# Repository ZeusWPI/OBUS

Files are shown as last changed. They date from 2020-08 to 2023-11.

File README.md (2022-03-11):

# Ontmijnen van een Bom vereist Uitstekende Samenwerking

You see an armed time bomb but don't know how to disarm it. Your friends found a manual to defuse the bomb and you have them on call. This is the premise of the game OBUS, a hardware project by [Zeus WPI](https://zeus.ugent.be). Inspired by the amazing software game [Keep Talking and Nobody Explodes](https://www.keeptalkinggame.com/).

## Get started writing a module

These are the instructions for building your own OBUS module with an Arduino Nano v3 and the custom PCB. If
you're using other hardware, you might need to do some things differently.

0. (Read the "[Getting started guide](docs/GETTING_STARTED.md)" to get a general idea of how OBUS works.)
1. [Install](https://www.arduino.cc/en/Guide/#install-the-arduino-desktop-ide) the Arduino IDE.
2. Clone this repository with Git in a permanent location on your drive.
3. Symlink the library: `ln -s /ABSOLUTE/PATH/TO/REPO/lib /PATH/TO/Arduino/libraries/obus`
  (on most Linux distro's, this the Arduino folder is in `$HOME/Arduino`)
4. Follow [these steps](https://github.com/autowp/arduino-mcp2515/#software-usage) to install the CAN library
5. Execute `./src/new_module.sh` to create a new module. When asked for a type, you'll probably want to choose 'puzzle'.
6. Edit the newly generated .ino file, either in the Arduino IDE or in your own editor.
7. In the Arduino IDE, select the correct board (Arduino Nano) and processor (ATmega328P (Old Bootloader)). After that,
   flash your code to the Arduino and test it out.
8. On some Linux distributions, you'll need to prevent BRLTTY from taking over the serial adapter because BRLTTY thinks it's a Braille keyboard. You can do this by uninstalling it (`pacman -R brltty`) or by [disabling it and then rebooting](https://unix.stackexchange.com/questions/670636/unable-to-use-usb-dongle-based-on-usb-serial-converter-chip).
9. If you get permission errors, try adding yourself to the dialout or uucp (Arch Linux) group

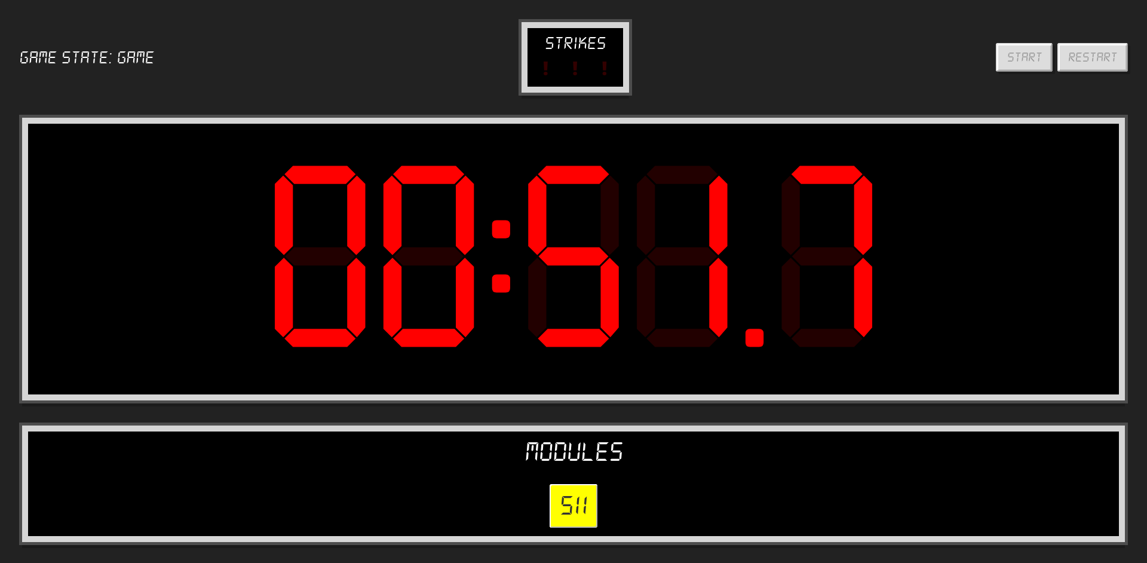
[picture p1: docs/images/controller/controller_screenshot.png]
A screenshot of the OBUS controller web page, showing a countdown timer, a list of connected modules and the strikes


## Background
### Game

The game is played by at least two players. The goal is to defuse a bomb,
this is accomplished by defusing every module on that bomb before the bomb
timer runs out.

There are two roles:

- Expert: this person can read the manual about how to defuse the bomb, but cannot see nor interact with the bomb
- Defuser: this person can see and interact with the bomb, but cannot read the manual

These two roles can communicate with each other. To successfully defuse the bomb, they must
communicate efficiently and clearly. If a mistake is made, the team gets a strike.
If they get too many strikes or the timer runs out, the bomb explodes.

## Common wiring between all modules

- CAN-H: red on JST 3 pin connectors, purple on CAN wire
- CAN-L: white on JST 3 pin connectors, brown on CAN wire
- +12V: red on 2 pin JST connector and power wire
- ground: black on 2 pin JST connector, no color on power wire

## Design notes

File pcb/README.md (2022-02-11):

# OBUS PCB

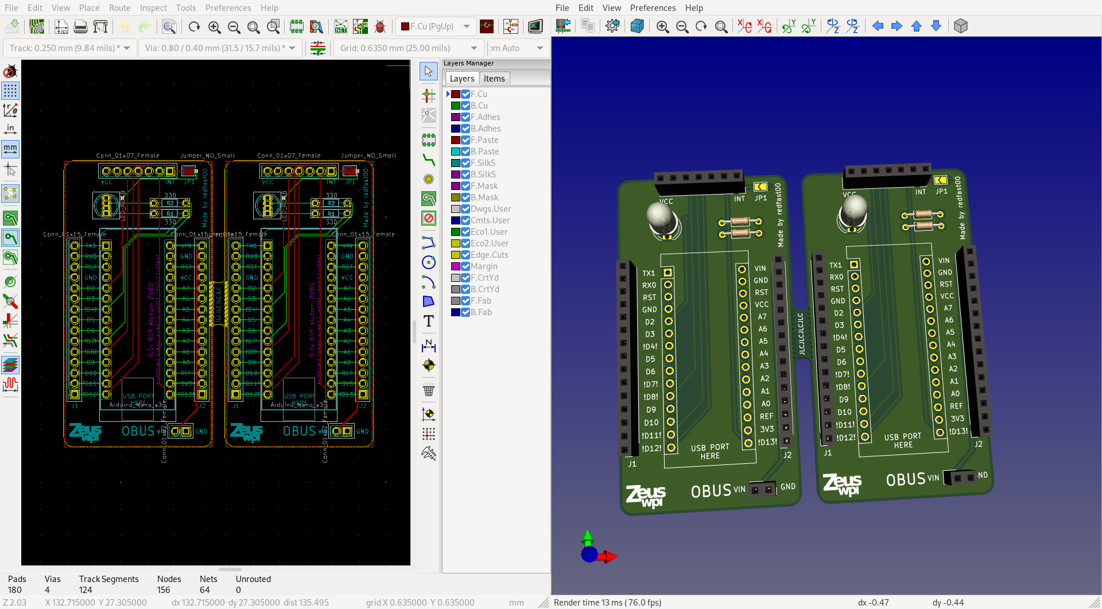
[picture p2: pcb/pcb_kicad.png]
The panelized OBUS PCB


In order to make it easier for our members to get started creating their own OBUS module,
we designed and ordered PCBs they can use instead of having to wire up the basics
on a breadboard. The PCB accomodates an Arduino Nano V3 (and clones), an MCP2515 CAN-bus module
and an RGB LED. The LED and CAN bus module are connected to pins on the
Arduino Nano. All pins on the Arduino Nano are connected to the ajacent pin socket so
they can easily be accessed when breadboarding.
The pins already used by the OBUS framework are marked with exclamation marks. This does
not mean they can't be used for other purposes anymore, just that you need to pay
attention when using them: for example the SPI pins can be used for other devices, but
the LED pins can't. While picking the pins, we made sure to use the least useful pins
for the OBUS framework: we tried to pick as few PWM pins as possible, didn't pick any I2C
pins, ...

## Connecting the parts on the socket.

We tried our best to make the board as self-explanatory as possible. When pushing the
Arduino into its socket, make sure it's in the correct orientation. When connecting the
CAN bus module, you'll need to flip it on its back, then look at the silk screen on both
the OBUS PCB and the CAN module so that the INT pin is connected in the INT socket hole.

By default, the INT pin on the CAN module is not connected to the Arduino in order to
save pins. If you want to connect the INT pin to pin D2 on the Arduino, you can bridge
the jumper on the top right of the board with some solder.

### Component list per board

- 2 1x15 2.54mm pin sockets, we recommend 4 sockets so you can socket the Arduino as well
- 1 1x07 2.54mm pin socket
- 1 1x02 2.54mm pin socket
- 1 common cathode 5mm RGB LED, pin order RCGB
- 2 330 ohm through hole resistors

## TODO for next board iteration

There is still some space left over at the top and sides of the board, so use it:

- Add extra connection holes for every Arduino pin where wires can be soldered semi permanently on the sides of the board
- Add copper pads/holes to make a "perfboard" on the bottom of the board (with 2.54mm spacing, like a breadboard)
- Add holes to solder wires in for the status RGB LED in case we don't want this on the main PCB
- Add silkscreen with pin names on back of PCB
- Add SMD footprints for LED resistors
- Add holes for M3 bolts
- Add logo on back

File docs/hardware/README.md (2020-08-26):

# Hardware documentation

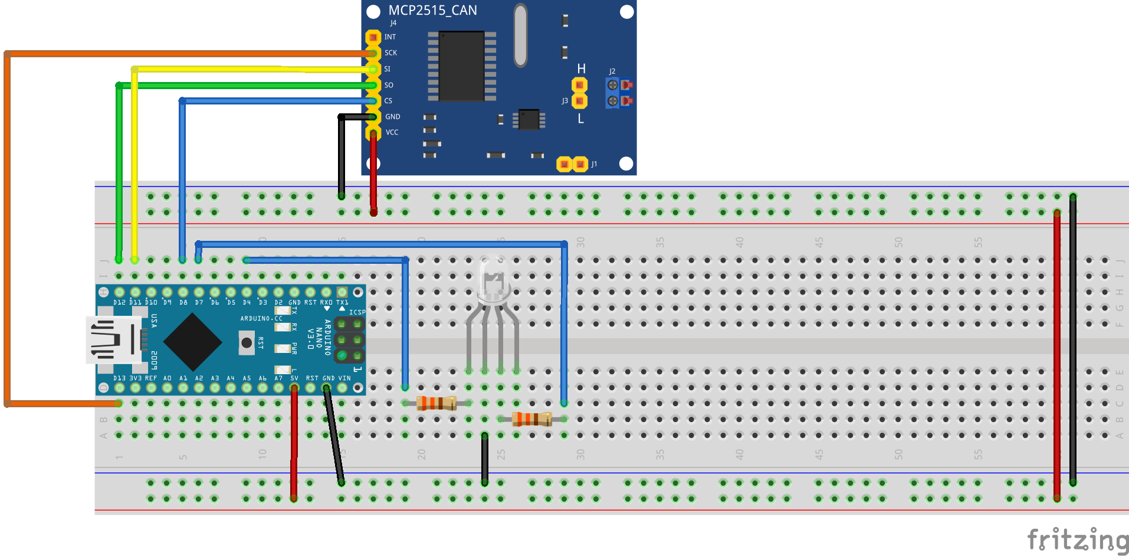
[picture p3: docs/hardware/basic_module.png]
Breadboard with Arduino Nano and CAN module


## Parts of basic module

- 2x 330 ohm resistor
- RGB common cathode LED
- MCP2515 CAN module
- Arduino nano (clone)

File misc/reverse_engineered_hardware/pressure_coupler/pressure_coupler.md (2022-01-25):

# Pressure coupler

## Left side (facing front panel)

From top to bottom:

- input on/off -> connected to single white wire, switch is between that and ground
- bridge balance -> connected to blue wire. This is a voltage divider between ground and VCC, read this with `analogRead()`
- calibration -/off/+ -> connected to twisted white/orange wire, connects
  the white wire to ground, nothing to ground or the orange wire to ground
- multichoice switch -> has 16 positions, each yellow wire is a bit of the number of the position
  so for example, if the switch is in the third position (so 2 when counting 0-based, or 0010 in binary),
	wire 2 will be connected to ground, all other wires will be left floating

Red is connected to VCC (5V), black to ground

## Right side

Switches are connected to white wires (2 positions) or white and orange wires (3 positions). Knobs are connected to blue wires.

Switches connect to ground or keep wire floating. Knobs are a voltage divider between ground (black) and VCC (red).

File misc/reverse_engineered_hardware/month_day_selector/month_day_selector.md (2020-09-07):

brown = GND
blue = VCC

yellow = clock
orange = q8 on chip 4
green = read data from buttons

The PCB contains 4 TC4021BP shift register connected in series. To put the current state of the board into the registers, pulse the green wire. Then read bit by bit by first reading from the orange wire, then pulsing the yellow clock wire to advance every bit

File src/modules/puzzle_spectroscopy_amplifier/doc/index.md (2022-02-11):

# Spectroscopy Amplifier (model 2020)

Schrijf de handleiding voor je module hier. Kijk gerust naar de handleiding
voor de "Doolhof"-module (`src/modules/puzzle_maze/doc/index.md`)

Hieronder wat voorbeelden van markup die je kan gebruiken. Daarnaast kan je ook LaTeX
gebruiken (zie bijvoorbeeld de "Doolhof"-module)

Use drawings! Create the docs/images/your_module directory, put your image there and include them like this:



Use tables! Write them like this:

| Symbol | Action to take |
|---|---|
|  | Do nothing |
|  | Press the red button |
|  | Press the yellow button |

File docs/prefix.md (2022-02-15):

# Bommen ontmantelen

De bom ontploft wanneer de timer 00:00.0 bereikt of wanneer er te veel fouten gemaakt zijn.
Je kan de bom onschadelijk maken door, voor de tijd op is, alle modules uit te schakelen.

## Modules

Elke bom bevat modules. Deze zijn aangegeven via een oranje halve cylinder waarin een LED brandt.
Is de LED groen-geel, dan moet de module nog uitgeschakeld worden. Dit kan door de stappen
in de handleiding te volgen. De volgorde waarin de modules opgelost worden, maakt niet uit.

## Infomodules

Het kan zijn dat je voor het oplossen van bepaalde modules informatie nodig hebt die op een andere
module (een infomodule) staat. Infomodules hebben geen oranje halve cylinder en kunnen niet opgelost worden: je
kan er enkel informatie op aflezen. Wanneer je informatie uit een infomodule nodig hebt, zal er
verwezen worden naar de pagina in de appendix die over die infomodule gaat.

## Fouten

Wanneer fouten gemaakt worden tijdens het ontmantelen van de bom, zal dit aangegeven worden op
het scherm van de bom: per fout zal er een uitroepteken bovenaan rood worden. Zijn er te veel fouten gemaakt, dan ontploft de bom.

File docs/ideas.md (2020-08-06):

# OBUS modules

## Modules

Modules use the standard communication protocol. Extensions in the form of additional message types can be used to request extra information and for configuration.
Only the ID/address should be configured on the modules themselves (with DIP switches or something like that).

## Controller

The controller could have an interface (GUI/CLI/web app) with a control panel and/or scoreboard, to enable competition between different teams.
Spectators could follow along in real time.
The controller could be a Raspberry PI to have easy networking.

## Needy

- TBD

## Puzzles

- Midgard's dial
- Big emergency button (or other big button)
- Big "mechanical knife switch"
- Timer (with metronome)
- Snake
- Boolean logic
- Last-minute modules
- Modules that require actions at specific dates
- Simon says
- Don't push this button
- Morse
- Module with a few resistors that you have to connect at the correct locations

### Essentials (for PoC):

- Buttons
- LCD + buttons
- 7-segment display
- DPAD + enter
- OLED display
- Console (debug?)

## Documentation

Documentation with the look of a datasheet of the corporation "Zeus WPI" (retro style).

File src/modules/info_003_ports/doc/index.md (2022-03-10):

# Appendix C: Poorten

De donkerblauwe, balkvormige poortmodule kan poorten tonen of verbergen. De module mag niet afgelezen
worden wanneer die in beweging is.

\begin{figure}[!b]
  \centering
	\includegraphics[width=10cm,height=5cm,keepaspectratio]{./info_003_ports/ports.png}
\end{figure}

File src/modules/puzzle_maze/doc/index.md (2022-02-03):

# Doolhof

\begin{figure}[!b]
  \centering
	\includegraphics[width=24cm,height=5cm,keepaspectratio]{./puzzle_maze/description.png}
\end{figure}

- Zoek het juiste doolhof en oriëntatie van dit doolhof aan de hand van de lichten buiten het rooster
  die overeenkomen met de cirkelvormige markeringen op de rand van de doolhofkaarten.

- Het knipperend licht binnen het rooster is de bestemming, het licht binnen het rooster dat blijft branden
  is je karakter. Navigeer je karakter naar de bestemming met de gele knoppen, zonder
	dat die door de muren van het doolhof gaat. Let wel, de ontmijner kan de muren niet zien!

## Doolhofkaarten

\begin{center}
    \includegraphics[width=10cm, height=10cm,keepaspectratio]{./puzzle_maze/maze.png}
\end{center}

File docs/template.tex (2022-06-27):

% Options for packages loaded elsewhere
\PassOptionsToPackage{unicode$for(hyperrefoptions)$,$hyperrefoptions$$endfor$}{hyperref}
\PassOptionsToPackage{hyphens}{url}
$if(colorlinks)$
\PassOptionsToPackage{dvipsnames,svgnames,x11names}{xcolor}
$endif$
$if(dir)$
$if(latex-dir-rtl)$
\PassOptionsToPackage{RTLdocument}{bidi}
$endif$
$endif$
$if(CJKmainfont)$
\PassOptionsToPackage{space}{xeCJK}
$endif$
%
\documentclass[
$if(fontsize)$
  $fontsize$,
$endif$
$if(lang)$
  $babel-lang$,
$endif$
$if(papersize)$
  $papersize$paper,
$endif$
$if(beamer)$
  ignorenonframetext,
$if(handout)$
  handout,
$endif$
$if(aspectratio)$
  aspectratio=$aspectratio$,
$endif$
$endif$
$for(classoption)$
  $classoption$$sep$,
$endfor$
]{$documentclass$}
$if(beamer)$
$if(background-image)$
\usebackgroundtemplate{%
  %
}
$endif$
\usepackage{pgfpages}
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
$endif$
$if(strikeout)$
$-- also used for underline
\usepackage[normalem]{ulem}
% Avoid problems with \sout in headers with hyperref
\pdfstringdefDisableCommands{\renewcommand{\sout}{}}
$endif$
\setlength{\emergencystretch}{3em} % prevent overfull lines
\providecommand{\tightlist}{%
  \setlength{\itemsep}{0pt}\setlength{\parskip}{0pt}}
$if(numbersections)$
\setcounter{secnumdepth}{$if(secnumdepth)$$secnumdepth$$else$5$endif$}
$else$
\setcounter{secnumdepth}{-\maxdimen} % remove section numbering
$endif$
$if(beamer)$
$else$
$if(block-headings)$
% Make \paragraph and \subparagraph free-standing
\ifx\paragraph\undefined\else
  \let\oldparagraph\paragraph
  \renewcommand{\paragraph}[1]{\oldparagraph{#1}\mbox{}}
\fi
\ifx\subparagraph\undefined\else
  \let\oldsubparagraph\subparagraph
  \renewcommand{\subparagraph}[1]{\oldsubparagraph{#1}\mbox{}}
\fi
$endif$
$endif$
$if(pagestyle)$
\pagestyle{$pagestyle$}
$endif$
$if(csl-refs)$
\newlength{\cslhangindent}
\setlength{\cslhangindent}{1.5em}
\newlength{\csllabelwidth}
\setlength{\csllabelwidth}{3em}
\newlength{\cslentryspacingunit} % times entry-spacing
\setlength{\cslentryspacingunit}{\parskip}
\newenvironment{CSLReferences}[2] % #1 hanging-ident, #2 entry spacing
 {% don't indent paragraphs
  \setlength{\parindent}{0pt}
  % turn on hanging indent if param 1 is 1
  \ifodd #1
  \let\oldpar\par
  \def\par{\hangindent=\cslhangindent\oldpar}
  \fi
  % set entry spacing
  \setlength{\parskip}{#2\cslentryspacingunit}
 }%
 {}
\usepackage{calc}
\newcommand{\CSLBlock}[1]{#1\hfill\break}
\newcommand{\CSLLeftMargin}[1]{\parbox[t]{\csllabelwidth}{#1}}
\newcommand{\CSLRightInline}[1]{\parbox[t]{\linewidth - \csllabelwidth}{#1}\break}
\newcommand{\CSLIndent}[1]{\hspace{\cslhangindent}#1}
$endif$
$for(header-includes)$
$header-includes$
$endfor$
$if(lang)$
\ifXeTeX
  % Load polyglossia as late as possible: uses bidi with RTL langages (e.g. Hebrew, Arabic)
  \usepackage{polyglossia}
  \setmainlanguage[$for(polyglossia-lang.options)$$polyglossia-lang.options$$sep$,$endfor$]{$polyglossia-lang.name$}
$for(polyglossia-otherlangs)$
  \setotherlanguage[$for(polyglossia-otherlangs.options)$$polyglossia-otherlangs.options$$sep$,$endfor$]{$polyglossia-otherlangs.name$}
$endfor$
\else
  \usepackage[$for(babel-otherlangs)$$babel-otherlangs$,$endfor$main=$babel-lang$]{babel}
% get rid of language-specific shorthands (see #6817):
\let\LanguageShortHands\languageshorthands
\def\languageshorthands#1{}
$if(babel-newcommands)$
  $babel-newcommands$
$endif$
\fi
$endif$
\ifLuaTeX
  \usepackage{selnolig}  % disable illegal ligatures
\fi
$if(dir)$
\ifXeTeX
  % Load bidi as late as possible as it modifies e.g. graphicx
  \usepackage{bidi}
\fi
\ifPDFTeX
  \TeXXeTstate=1
  \newcommand{\RL}[1]{\beginR #1\endR}
  \newcommand{\LR}[1]{\beginL #1\endL}
  \newenvironment{RTL}{\beginR}{\endR}
  \newenvironment{LTR}{\beginL}{\endL}
\fi
$endif$
$if(natbib)$
\usepackage[$natbiboptions$]{natbib}
\bibliographystyle{$if(biblio-style)$$biblio-style$$else$plainnat$endif$}
$endif$
$if(biblatex)$
\usepackage[$if(biblio-style)$style=$biblio-style$,$endif$$for(biblatexoptions)$$biblatexoptions$$sep$,$endfor$]{biblatex}
$for(bibliography)$
\addbibresource{$bibliography$}
$endfor$
$endif$
$if(nocite-ids)$
\nocite{$for(nocite-ids)$$it$$sep$, $endfor$}
$endif$
\usepackage{csquotes}

$if(title)$
\title{$title$$if(thanks)$\thanks{$thanks$}$endif$}
$endif$
$if(subtitle)$
$if(beamer)$
$else$
\usepackage{etoolbox}
\makeatletter
\providecommand{\subtitle}[1]{% add subtitle to \maketitle
  \apptocmd{\@title}{\par {\large #1 \par}}{}{}
}
\makeatother
$endif$
\subtitle{$subtitle$}
$endif$
\author{$for(author)$$author$$sep$ \and $endfor$}
\date{$date$}
$if(beamer)$
$if(institute)$
\institute{$for(institute)$$institute$$sep$ \and $endfor$}
$endif$
$if(titlegraphic)$
\titlegraphic{}
$endif$
$if(logo)$
\logo{}
$endif$
$endif$

\usepackage{wrapfig}
\usepackage{multicol}

\begin{document}
$if(has-frontmatter)$
\frontmatter
$endif$
$if(title)$
$if(beamer)$
\frame{\titlepage}
$else$
\maketitle
$endif$
$if(abstract)$
\begin{abstract}
$abstract$
\end{abstract}
$endif$
$endif$

$for(include-before)$
$include-before$

$endfor$
$if(toc)$
$if(toc-title)$
\renewcommand*\contentsname{$toc-title$}
$endif$
$if(beamer)$
\begin{frame}[allowframebreaks]
$if(toc-title)$
  \frametitle{$toc-title$}
$endif$
  \tableofcontents[hideallsubsections]
\end{frame}
$else$
{
$if(colorlinks)$
\hypersetup{linkcolor=$if(toccolor)$$toccolor$$else$$endif$}
$endif$
\setcounter{tocdepth}{$toc-depth$}
\tableofcontents
}
$endif$
$endif$
$if(lof)$
\listoffigures
$endif$
$if(lot)$
\listoftables
$endif$
$if(linestretch)$
\setstretch{$linestretch$}
$endif$
$if(has-frontmatter)$
\mainmatter
$endif$
$body$

$if(has-frontmatter)$
\backmatter
$endif$
$if(natbib)$
$if(bibliography)$
$if(biblio-title)$
$if(has-chapters)$
\renewcommand\bibname{$biblio-title$}
$else$
\renewcommand\refname{$biblio-title$}
$endif$
$endif$
$if(beamer)$
\begin{frame}[allowframebreaks]{$biblio-title$}
  \bibliographytrue
$endif$
  \bibliography{$for(bibliography)$$bibliography$$sep$,$endfor$}
$if(beamer)$
\end{frame}
$endif$

$endif$
$endif$
$if(biblatex)$
$if(beamer)$
\begin{frame}[allowframebreaks]{$biblio-title$}
  \bibliographytrue
  \printbibliography[heading=none]
\end{frame}
$else$
\printbibliography$if(biblio-title)$[title=$biblio-title$]$endif$
$endif$

$endif$
$for(include-after)$
$include-after$

$endfor$
\end{document}

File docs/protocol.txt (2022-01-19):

______________________________________

Recap: message in CAN protocol
  ↓ 11b     ↓ 64b (8 bytes)
+----+-----------------+ - - -
| id |      body       | don’t care for now
+----+-----------------+ - - -

Priority is controlled by the ID: if a message with a higher ID is on the bus, lower messages will
be silenced due to the design of CAN.

______________________________________

OBUS message specification

ID:
b bb bbbbbbbb
|  |     ↓
|  ↓     module-ID: 2⁸=256
↓  type: 2²=4
priority bit (so that each type can send priority messages if need be, 0 = high priority, 1 = low priority)

    type:
    - 0 module-ID 0: controller, >0: info
    - 1 puzzel
    - 2 needy
    - 3 reserved for future use

Payload:
[ B B B B  B B B B ]
  -
  ↓
 type of the message (per module type)

- - - - - - - - - - - - - - - - - - -

Types for controller:

    - 0 acknowledge register message
      [ X B B B  B B B B ]
          - - ----------
          | ↓  reserved
          ↓ module ID
       type

    - 1 hello
      [ X B B B  B B B B ]
          --------------
             reserved

    - 2 game start
      [ X B B B  B B B B ]
          -------- - - -
   time left in ms ↓ ↓ #puzzle modules
            #strikes #max strikes

    - 3 state (every x ms – e.g. in the middle of each second)
      [ X B B B  B B B B ]
          -------- - - -
   time left in ms ↓ ↓ #puzzle modules left
            #strikes #max strikes

    - 4-6 solved, timeout, strikeout
      [ X B B B  B B B B ]
          -------- - - -
          end time ↓ ↓ #puzzle modules left
            #strikes #max strikes

    - 7 info start
      [ X B B B  B B B B ]
          -------- -----
              ↓    reserved
       random seed

    - 8-255 reserved

- - - - - - - - - - - - - - - - - - -

Types for info:

    These are managed by MOANA: the Modules of OBUS Authority for Numbers Assignment.
    You can reach MOANA in the ~obus Mattermost channel.

    (none yet)

- - - - - - - - - - - - - - - - - - -

Types for modules:

    - 0 register
      [ X B B B  B B B B ]
          --------------
             reserved

    - 1 strike
      [ X B B B  B B B B ]
          ↓ -----↓------
    #strikes  reserved

    - 2 solved (not for needy modules)
      [ X B B B  B B B B ]
          --------------
             reserved

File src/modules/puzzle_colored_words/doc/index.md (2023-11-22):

# Gekleurde woorden

- Druk op het juiste moment op de juiste knop.
- Er zal een reeks van 8 woorden getoond worden in verschillende kleuren. Elk woord wordt 1 seconde getoond. Na de reeks volgt er een zwart scherm, waarna de reeks zich herhaalt.
- De mogelijke kleuren zijn: rood, groen, blauw, wit, paars, grijs en geel.
- Er moet precies 1 knop 1 keer ingedrukt worden om deze module op te lossen.
- De kleur van het eerste woord in de reeks bepaalt
welke van de onderstaande regels je dient te volgen.
- Pas enkel de bovenste geldige regel toe uit het blok dat van toepassing is.
- \warning{} **De rode knop is 'Ja', de groene knop is 'Nee'.** \warning{}

**De kleur van het eerste woord in de reeks is rood**

1. Als de kleur van een woord overeenkomt met het woord, druk dan "Nee" bij het eerste woord in de reeks waar dit zo is.
2. Anders, als er twee of meer woorden in de reeks rood gekleurd zijn, druk dan "Ja" bij het laatst rood gekleurde woord.
3. Anders, druk "Nee" bij het laatste woord.

**De kleur van het eerste woord in de reeks is groen**

1. Als het woord "groen" blauw gekleurd is, druk dan "Nee" bij het eerste blauw gekleurde woord.
2. Anders, als het woord "rood" grijs of geel gekleurd is, druk dan "Nee" bij de eerste keer in de reeks waarin dit zo is.
3. Anders, als het woord "grijs" wordt opgevolgd door een woord dat wit of groen gekleurd is, druk dan "Ja" bij het eerste woord "grijs".
4. Anders, druk "Nee" op het eerste woord "paars" in de reeks.

**De kleur van het eerste woord in de reeks is blauw**

1. Als de kleur van het woord en het woord 4 of meer keer niet overeenkomen, druk dan "Ja" bij het vierde woord waarbij de kleur en het woord niet overeenkomen.
2. Anders, als twee opeenvolgende woorden dezelfde kleur hebben, druk dan "Nee" op het derde wooord.
3. Anders, als er meer dan 1 woord blauw gekleurd is, druk dan "Nee" bij het laatste blauw gekleurde woord.
4. Anders, druk "Ja" bij het eerste blauw gekleurde woord.

**De kleur van het eerste woord in de reeks is wit**

1. Als het vierde woord overeenkomt met de kleur van het tweede woord of de kleur van het zesde woord, druk dan "Nee" bij het eerste woord dat groen gekleurd is of waar "groen" staat.
2. Anders, als er meer woorden geel gekleurd zijn dan er paars gekleurd zijn, druk dan "Nee" bij het eerste geel gekleurde woord.
3. Anders, als het vijfde woord blauw gekleurd is, druk dan op "Nee" bij het vierde woord.
4. Anders, druk op "Ja" bij het vierde woord.

**De kleur van het eerste woord is paars** 

1. Als het tweede of derde woord rood gekleurd is, druk dan "Ja" bij het eerste rood gekleurde woord.
2. Anders, druk "Nee" bij het eerste woord "grijs" dat niet wit gekleurd is indien mogelijk.
3. Indien niet mogelijk, druk "Nee" bij het eerste woord "wit".

**De kleur van het eerste woord is grijs**

1. Als de kleuren van twee opeenvolgende woorden gelijk zijn, druk dan "Ja" bij het laatste grijs gekleurde woord in de reeks.
2. Anders, als er een geel gekleurd woord in de reeks is en de kleur van het vijfde woord komt overeen met het vierde woord, druk dan "Ja" op het eerste geel gekleurde woord.
3. Anders, druk "Nee" bij het laatste paars gekleurde woord.

**De kleur van het eerste woord is geel** 

1. Als een woord in de reeks overeenkomt met de kleur van dat woord, druk dan "Ja" bij het eerste woord in de reeks waar dit zo is.
2. Anders, als er twee of meer geel gekleurde woorden zijn, druk dan "Ja" bij het laatste geel gekleurde woord.
3. Anders, druk "Nee" bij het eerste rood gekleurde woord.

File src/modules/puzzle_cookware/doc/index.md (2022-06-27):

# Cookware

Deze module toont 10 ingrediënten op het LCD-scherm waarvan er telkens maar één
tegelijk zichtbaar is. De bedoeling is om het unieke gerecht te vinden dat met
een combinatie van deze ingrediënten gemaakt kan worden. Dit gerecht moet je dan
klaarmaken door de ingrediënten toe te voegen en met de juiste techniek het
gerecht klaar te maken.

## Ingrediënten toevoegen

Met de next-knop (next-knop) kan je naar het
volgende ingrediënt springen. Als je het klaar te maken recept bepaald hebt, kan
je de juiste ingrediënten toevoegen door er naar toe te gaan en op de add-knop
(add-knop) klikken. Er komt dan onder het
ingrediënt de tekst "Added" te staan. De volgorde waarin de ingrediënten worden
toegevoegd is van geen belang. Als je een ingrediënt toevoegt dat niet in het
gerecht thuishoort wordt je hier niet voor gestraft. Om het weer te verwijderen
druk je opnieuw op de add-knop terwijl het ingrediënt zichtbaar is.

## Het gerecht klaarmaken

Wanneer alle ingrediënten toegevoegd zijn (en geen andere) klik je op de knop
die overeenkomt met de techniek die bij het gerecht staat. Omdat timing bij het
koken enorm belangrijk is, is het ook hier zo dat je op het juiste moment op die
knop moet klikken. Dit hangt af van het type gerecht en de techniek die gebruikt
wordt. Het laatste cijfer van de resterende tijd moet overeenkomen met het
cijfer dat je vindt in de onderstaande tabel.

| |  |  |  |  |
|:---|:---:|:---:|:---:|:---:|
| Voorgerecht | 4 | 3 | 7 | 1 |
| Soep | 0 | 1 | 5 | 6 |
| Vis | 8 | 9 | 4 | 5 |
| Vlees | 2 | 7 | 0 | 9 |
| Dessert | 8 | 2 | 3 | 6 |

\newpage{}

## Mogelijke ingrediënten

\begin{multicols}{3}
\begin{itemize}

  \item Veal
  \item Beef
  \item Quail
  \item Filet Mignon
  \item Crab
  \item Scallop
  \item Lobster
  \item Sole
  \item Eel
  \item Sea Bass
  \item Mussel
  \item Cod
  \item Pumpkin
  \item Zucchini
  \item Onion
  \item Tomato
  \item Eggplant
  \item Carrot
  \item Garlic
  \item Celery
  \item Morel
  \item Porcini
  \item Chantarelle
  \item Portobello
  \item Black Truffle
  \item Oyster Mushroom
  \item Black Trumpet
  \item Miller Mushroom
  \item Cloves
  \item Rosemary
  \item Thyme
  \item Bay Leaf
  \item Basil
  \item Dill
  \item Parsley
  \item Saffron
  \item Apricot
  \item Gooseberry
  \item Lemon
  \item Orange
  \item Raspberry
  \item Pear
  \item Blackberry
  \item Apple
  \item Cheese
  \item Chocolate
  \item Caviar
  \item Butter
  \item Olive Oil
  \item Cornichon
  \item Rice
  \item Honey
  \item Sour Cherry
  \item Strawberry
  \item Blood Orange
  \item Banana
  \item Grapes
  \item Melon
  \item Watermelon
\end{itemize}
\end{multicols}

## Gerechten

### Voorgerecht

 *  Mushroom Terrine  
   Morel, Chantarelle, Oyster Mushroom, Black Trumpet
 *  Scallop Poêlé  
   Scallop, Olive Oil
 *  Ratatouille  
   Zucchini, Tomato, Eggplant, Garlic, Bay Leaf
 *  Lobster Mousse  
   Scallop, Lobster, Dill
 *  Caprese Salad  
   Strawberry, Tomato, Cheese, Basil

### Soep

 *  Consommé  
   Cloves, Celery, Onion
 *  Pumpkin Velouté  
   Pumpkin, Black Truffle
 *  Carrot Potage  
   Carrot, Onion, Rice, Butter
 *  Crab Bisque  
   Crab, Tomato, Carrot, Celery, Olive Oil
 *  Cold Tomato Soup  
   Watermelon, Tomato, Dill

### Vis

 *  Sole Meunière  
   Sole, Caviar
 *  Eel Matelote  
   Eel, Bay Leaf, Parsley
 *  Bouillabaisse  
   Mussel, Lobster, Cod, Garlic, Saffron
 *  Sea Bass en Papillote  
   Sea Bass, Basil, Thyme, Olive Oil
 *  Seafood Tartare  
   Blood Orange, Lobster, Sea Bass, Olive Oil
 *  Sea Bass Poêlé  
   Grapes, Sea Bass, Zucchini, Chantarelle, Parsley

### Vlees

 *  Sweetbread Poêlé  
   Veal, Lemon, Porcini
 *  Beef Sauté  
   Cornichon, Eggplant, Zucchini, Beef
 *  Beef Bourguignon  
   Rosemary, Bay Leaf, Thyme, Garlic, Beef
 *  Stuffed Quail  
   Portobello, Rice, Porcini, Miller Mushroom, Parsley, Quail
 *  Filet Mignon Poêlé  
   Sour Cherry, Butter, Black Truffle, Rosemary, Cloves, Filet Mignon

### Dessert

 *  Chocolate Mousse  
   Chocolate, Lemon, Butter
 *  Fresh Fruit Compote  
   Pear, Apple, Apricot
 *  Crêpes Suzette  
   Orange, Honey, Butter
 *  Berries au Fromage  
   Cheese, Lemon, Gooseberry, Raspberry, Blackberry
 *  Warm Banana Soufflé  
   Banana, Butter, Honey
 *  Fruit Gelée  
   Melon, Pear, Gooseberry
 *  Tarte aux Fruits  
   Sour Cherry, Strawberry, Blood Orange, Banana, Grapes, Melon, Watermelon

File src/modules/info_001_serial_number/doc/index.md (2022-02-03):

# Appendix A: Serienummer

Het serienummer bestaat uit 7 willekeurige hoofdletters/cijfers, en bevat ten minste
één cijfer en één hoofdletter. Het wordt op een LCD-scherm getoond.

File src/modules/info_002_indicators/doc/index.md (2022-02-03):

# Appendix B: Indicatorlampen

\begin{figure}[!b]
  \centering
	\includegraphics[width=10cm,height=5cm,keepaspectratio]{./info_002_indicators/description.png}
\end{figure}

Er zijn 2 soorten indicatorlampen: gelabelde en gekleurde. De gelabelde lampen staan
bovenaan de module, de gekleurde onderaan.

## Gelabelde indicatorlampen

De labels zijn (in volgorde): `WPI`, `KEL`, `DER`, `ZEUS`, `JDV`, `QRV`, `PSE`, `DRV`.

## Gekleurde indicatorlampen

Mogelijke kleuren zijn:

\fcolorbox{black}{red}{\rule{0pt}{6pt}\rule{6pt}{0pt}} rood, \fcolorbox{black}{green}{\rule{0pt}{6pt}\rule{6pt}{0pt}} groen, \fcolorbox{black}{blue}{\rule{0pt}{6pt}\rule{6pt}{0pt}} blauw, \fcolorbox{black}{yellow}{\rule{0pt}{6pt}\rule{6pt}{0pt}} geel, \fcolorbox{black}{cyan}{\rule{0pt}{6pt}\rule{6pt}{0pt}} cyaan, \fcolorbox{black}{orange}{\rule{0pt}{6pt}\rule{6pt}{0pt}} oranje, \fcolorbox{black}{magenta}{\rule{0pt}{6pt}\rule{6pt}{0pt}} roze, \fcolorbox{black}{violet}{\rule{0pt}{6pt}\rule{6pt}{0pt}} paars

Indien je niet zeker bent wat de kleur is van een bepaalde gekleurde indicatorlamp,
kan je op de witte knop op de zijkant van de module drukken. Zolang deze knop ingedrukt is,
worden tijdelijk alle kleuren in de volgorde van het lijstje hierboven getoond en gaan de gelabelde
indicatorlampen uit. Wanneer in de handleiding verwezen wordt naar indicatorlampen, gaat
dit enkel over hun staat wanneer de knop niet ingedrukt is.

**Waarschuwing**: wanneer er in de handleiding verwezen wordt naar de kleur van indicatorlampen,
mag je enkel de gekleurde indicatorlampen in beschouwing nemen, niet de gelabelde indicatorlampen
(de leds in de gelabelde indicatorlampen zijn geel, maar deze tellen niet mee).

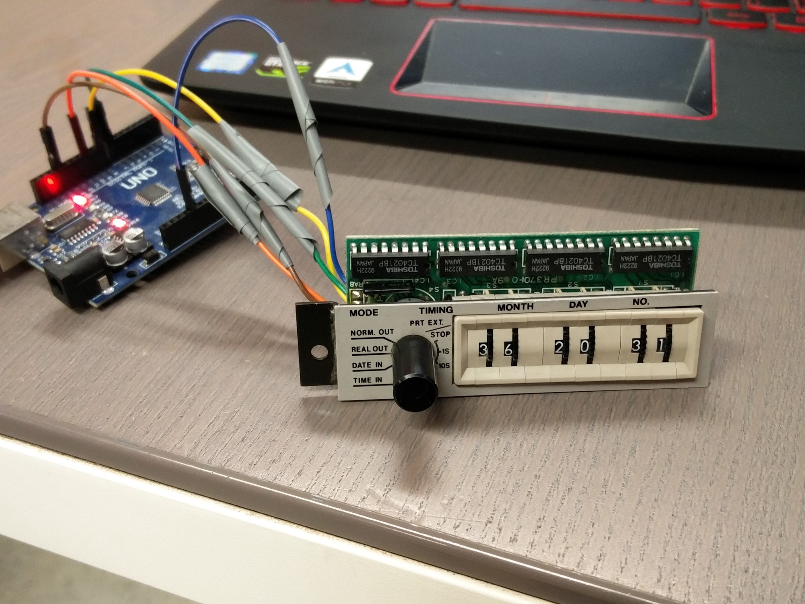
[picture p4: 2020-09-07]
misc/reverse_engineered_hardware/month_day_selector/month_day_selector.jpg

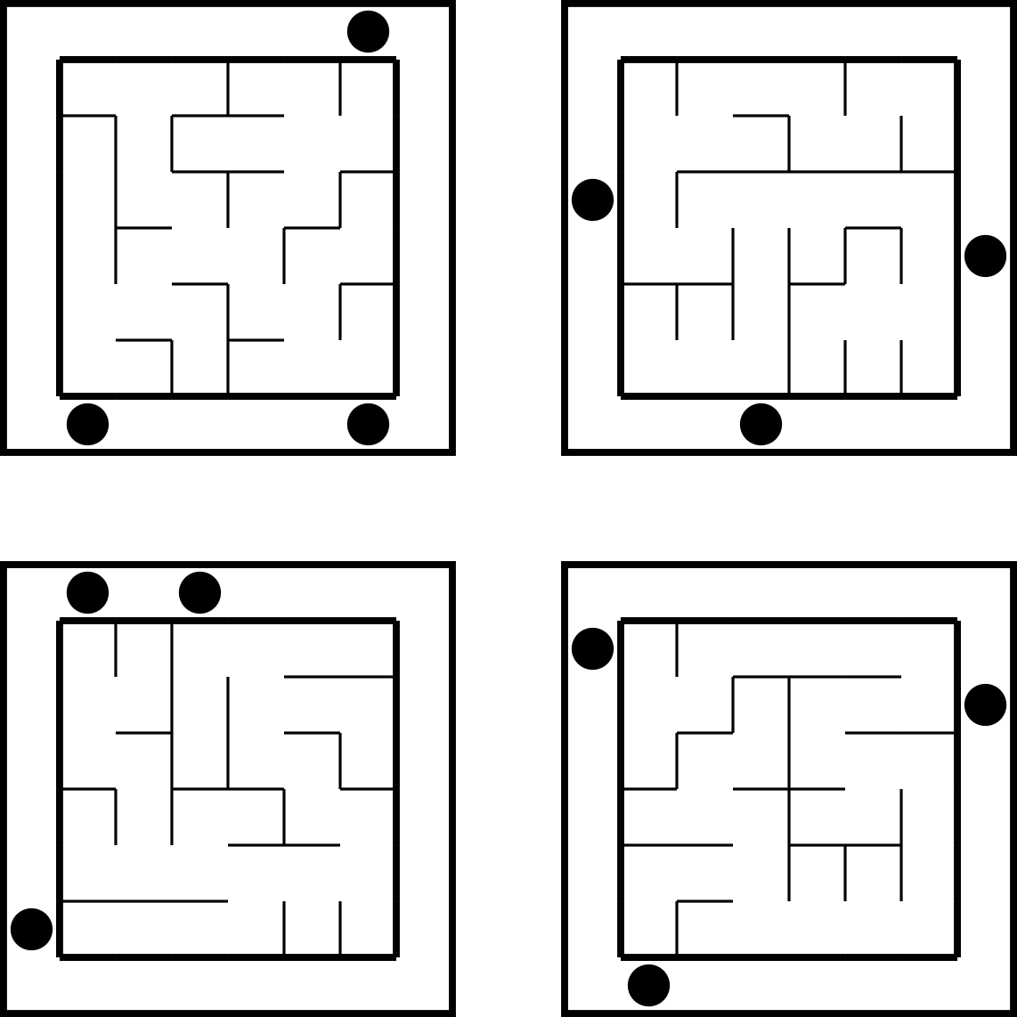
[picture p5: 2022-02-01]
docs/images/puzzle_maze/maze.png

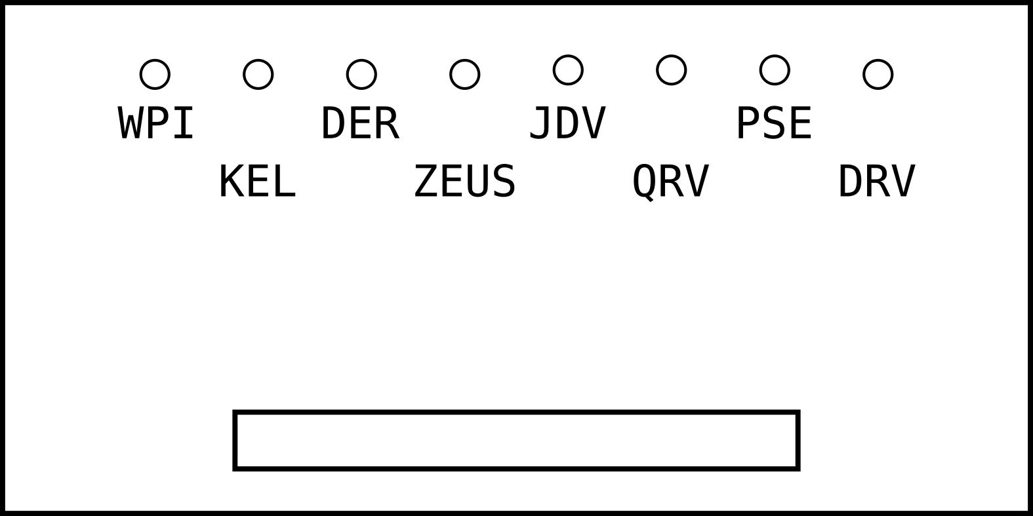
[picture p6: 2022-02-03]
docs/images/info_002_indicators/description.png

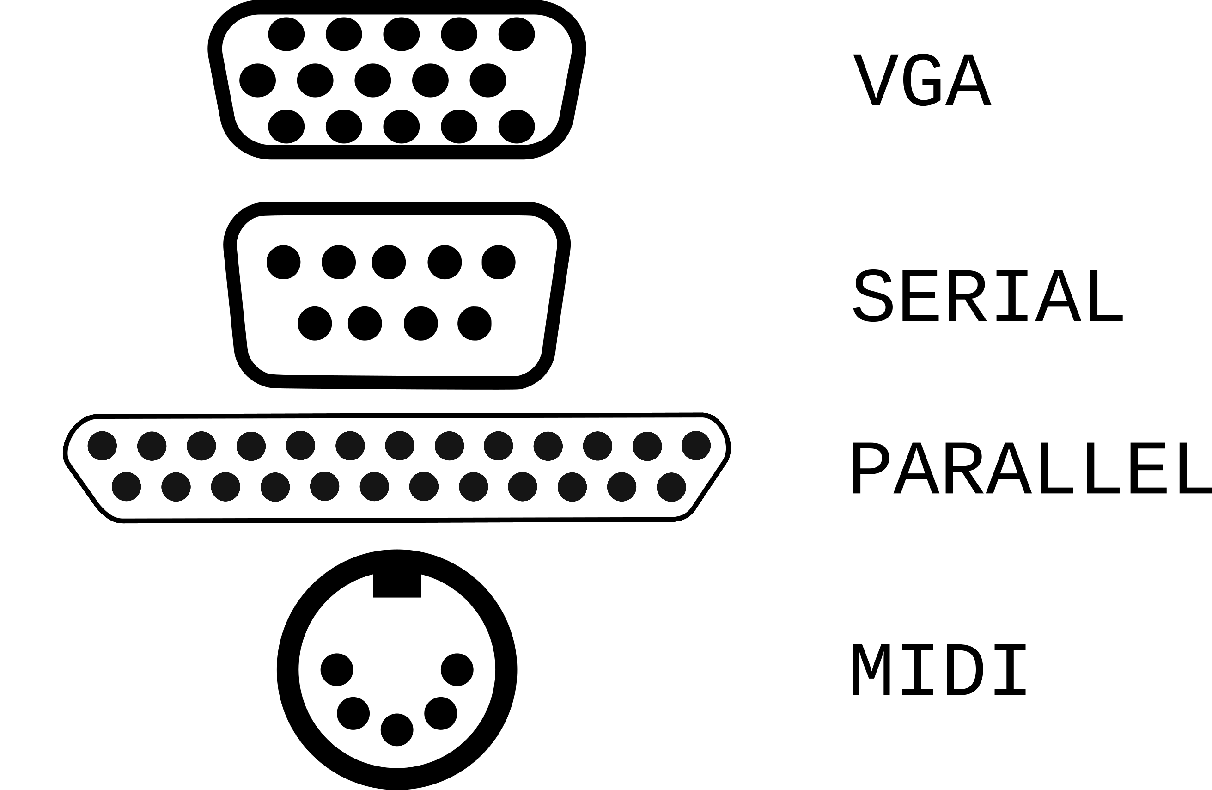
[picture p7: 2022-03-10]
docs/images/info_003_ports/ports.png

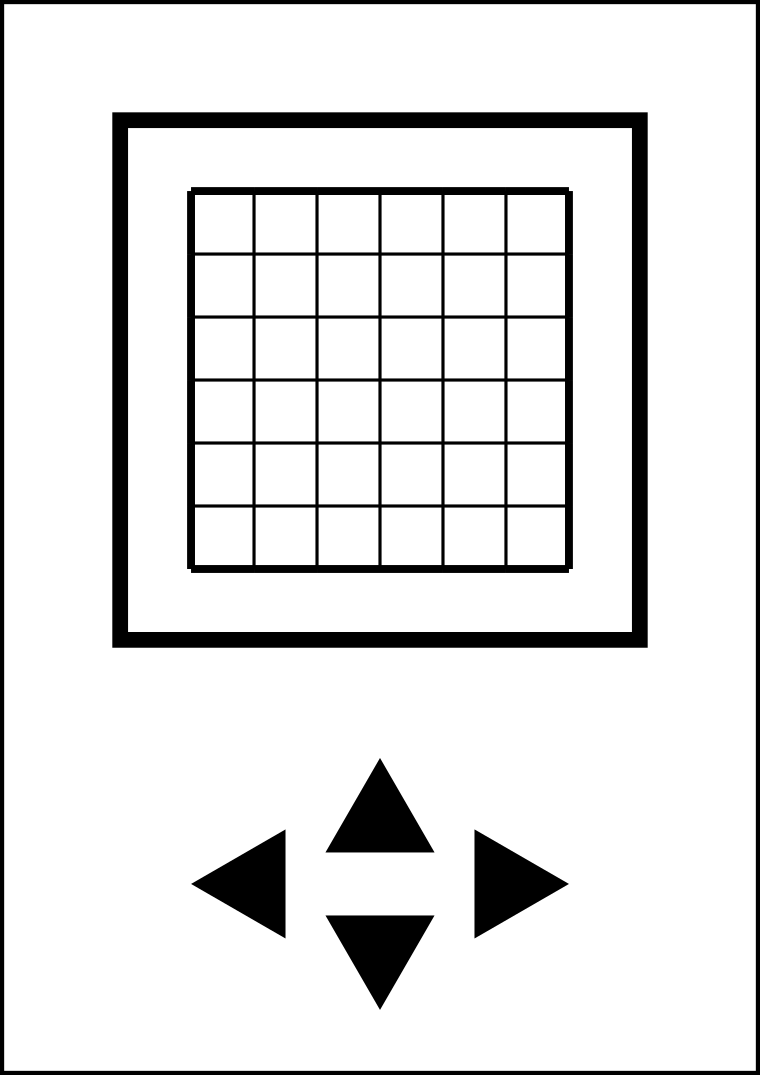
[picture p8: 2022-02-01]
docs/images/puzzle_maze/description.png

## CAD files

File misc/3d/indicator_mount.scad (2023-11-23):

$fn=100;
cut=100;



difference() {
	cylinder(d=40, h=12);
	translate([0, 0, -1]) union() {
		translate([-cut/2, 0]) cube(cut);
		translate([0, -10]) cylinder(d=5.1, h=cut);
		translate([0, -10]) cylinder(d=7, h=2);
	}

}

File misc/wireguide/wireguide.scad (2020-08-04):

$fn=100;
$high=30;
$offset_tool=3;
$offset_width=2.5;
$total_height=3;
$start_height=2;
$total_width=15;
$inner_width=11;

$eps = 0.01;

$idc_depth=4;

difference() {
  cube([20, 10, $total_height]);
  {
    {
      translate([$offset_tool, $offset_width, 0]) {
        for(i=[0:7]) {
          translate([$inner_width/7*i - 0.5, -5, $total_height]) rotate([-90, 0, 0]) {
           scale([1, 2, 1]) cylinder(h=$high, r=0.6);
          }
        }
        translate([($inner_width - $total_width) / 2, 0, $total_height-$start_height]) cube([$total_width, $idc_depth, $high]);
        color([0, 0, 1])  translate([3, $idc_depth - $eps, $total_height-$start_height - $eps]) cube([4, 1.2 + $eps, $high]);
        translate([5, 2, -1]) cylinder(h=$high, r=1);
      }
    }
  }
}

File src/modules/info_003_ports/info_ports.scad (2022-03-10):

$fn=100;
/* portheight = 37; */

// distance between mounting holes
mounting_hole_dist=[25, 25, 22, 46];

// size of physical ports
port_sizes=[30, 30, 29 ,53];
ports = len(port_sizes);
distance_between_ports=5;

cutout_radius=100; // not a physical dimension
cut=cutout_radius;
safe_angle=1;

eps=0.0001;

outer_radius=40; // outer radius of inner cylinder (the one with holes)
wall_thickness=2;
gear_height=13;

big_gear=30;
small_gear=14;
modul=1;
gear_distance=(big_gear+small_gear)*modul/2;

clip_thickness=7;
clip_offset=5;
clip_depth=1;


cylinder_height = sum(port_sizes)+distance_between_ports*(ports + 1);

function shl(x,y) = x * pow(2,y);
function shr(x,y) = floor(x * pow(2,-y));
function sum(v, i = 0, r = 0) = i < len(v) ? sum(v, i + 1, r + v[i]) : r;
function sum_up_to(v, idx, i = 0, r = 0) = (i < idx && i < len(v)) ? sum_up_to(v, idx, i + 1, r + v[i]) : r;

module rotating_cylinder() {
	echo("window size = ", 2 * (outer_radius - wall_thickness)*cos(90 + safe_angle - 360 / pow(2, ports + 1)));
	difference() {
		union() {
			/* %translate([0, 0, cylinder_height-0.005]) small_gear_cylinder(); */


			%translate([0, gear_distance, cylinder_height-0.005]) rotate([0, 0, 12.5]) {
				extragear();
			}


			cylinder(r=outer_radius, h=cylinder_height);
		}
		rotate([0, 0, (360 / 2^ports)*2]) union() {
			// hex hole for small gear
			translate([0, 0, cylinder_height - wall_thickness -distance_between_ports - 0.05]) cylinder(r=5, h=100, $fn=6);

			translate([0, 0, -eps]) cylinder(r=outer_radius-wall_thickness, h=cylinder_height - distance_between_ports + eps*2);
			for (rot=[0:pow(2, ports)]) {
				for (bit=[0:(ports - 1)]) {
					if (shr(rot, ports - 1 - bit) % 2 == 1) {
						current_height = sum_up_to(port_sizes, bit) + (bit + 1)*distance_between_ports;
						translate([0, 0, current_height])
						rotate([0,0,(360 / pow(2, ports))*rot])
						linear_extrude(height = port_sizes[bit]) {
					  	polygon(points=[[0,0],[cutout_radius*sin(90 + safe_angle - 360 / pow(2, ports + 1)), cutout_radius*cos(90 + safe_angle - 360 / pow(2, ports + 1))],[cutout_radius*sin(90 - safe_angle + 360 / pow(2, ports + 1)),cutout_radius*cos(90 - safe_angle + 360 / pow(2, ports + 1))]]);
						}
					}
				}
			}
		}
	}
}

// http://sammy76.free.fr/conseils/electronique/arduino/SG90.php
clearance=0.5;
size_outer = 2*(outer_radius+wall_thickness+clearance);


// Print upside-down
module small_gear_cylinder() {
	b_diam=5;
	difference() {
		union() {
			cylinder(h=gear_height, r=7);
			translate([0, 0, b_diam/2]) rotate([0, 90, 0]) cylinder(d=b_diam, h=25);
			cylinder(d=10-clearance, h=gear_height+5, $fn=6);
			mirror(v=[0, 0, 1]) cylinder(r=5-clearance/2, h=wall_thickness+distance_between_ports+2-5);
		}
		mirror(v=[0, 0, 1]) cube([3, 5, 12], center=true);
	}
	
}

ignore_height=4;
ignore_diameter=11.8;
extra_ignore_part=2.9;
distance_to_mount=22.7 - 15.9 - 2.5;

module container() {
	translation_outer = -outer_radius - wall_thickness - clearance;
	module clip_hole() {
		cube([clip_thickness+clearance, 100, 10+1]);
		translate([0, -clip_depth-clearance, 10]) cube([clip_thickness+clearance, 100, 10+clearance]);
	}
	echo("height of box = ", cylinder_height + clearance + gear_height + clearance + ignore_height +  distance_to_mount)
	echo("width of box = ", size_outer);
	difference() {
	 translate([translation_outer, translation_outer, 0]) cube([size_outer, size_outer, cylinder_height + clearance + gear_height + clearance + ignore_height +  distance_to_mount]);
	 union() {
     // hole for inner cylinder
		 translate([0, 0, -eps]) cylinder(r=outer_radius + clearance, h=cylinder_height + gear_height + clearance*2 + eps);

		 // hole for main cylinder shaft
		 translate([0, 0, cylinder_height]) cylinder(r=5+clearance/2, h=50);

		 // hole for gear shaft
		 translate([0, gear_distance, cylinder_height]) {
			 hull() {
				 cylinder(r=(ignore_diameter+clearance)/2, h=50);
				 translate([(ignore_diameter)/2+extra_ignore_part, 0, 0]) cylinder(r=extra_ignore_part+clearance, h=50);
			 }
		 }

		 // rectangular hole for motor

		 translate([-5.9 - clearance/2, gear_distance - 11.8/2 - clearance/2, cylinder_height + clearance + gear_height + clearance + ignore_height]) {
			 cube([22.5 + clearance, 11.8 + clearance, distance_to_mount]);
		 }

		 // indentations on side for clips
		 translate([clip_offset + translation_outer - clearance/2, size_outer/2 - wall_thickness, 0]) {
			 clip_hole();
		 }
		 translate([size_outer/2 -clip_offset - clip_thickness - clearance/2, size_outer/2 - wall_thickness, 0]) {
			 clip_hole();
		 }
		 mirror(v=[0, 1, 0]) {
			 translate([clip_offset + translation_outer - clearance/2, size_outer/2 - wall_thickness, 0]) {
				 clip_hole();
			 }
			 translate([size_outer/2 -clip_offset - clip_thickness - clearance/2, size_outer/2 - wall_thickness, 0]) {
				 clip_hole();
			 }
		 }



		 // holes on side for ports
		 rot = 0;
		 for (bit=[0:(ports - 1)]) {
			 current_height = sum_up_to(port_sizes, bit) + (bit + 1)*distance_between_ports;
			 translate([0, 0, current_height])
			 rotate([0,0,(360 / pow(2, ports))*rot])
			 linear_extrude(height = port_sizes[bit]) {
				 polygon(points=[[0,0],[cutout_radius*sin(90 + safe_angle - 360 / pow(2, ports + 1)), cutout_radius*cos(90 + safe_angle - 360 / pow(2, ports + 1))],[cutout_radius*sin(90 - safe_angle + 360 / pow(2, ports + 1)),cutout_radius*cos(90 - safe_angle + 360 / pow(2, ports + 1))]]);
			 }
		 }
	 	}
	}
}

module prism(l, w, h){
	polyhedron(
	  points=[[0,0,0], [l,0,0], [l,w,0], [0,w,0], [0,w,h], [l,w,h]],
	  faces=[[0,1,2,3],[5,4,3,2],[0,4,5,1],[0,3,4],[5,2,1]]
	);
 }

module clip(thickness=5, clip_depth=1) {
	translate([0, -wall_thickness, 0]) {
		translate([0, -clip_depth, 10]) prism(thickness, wall_thickness + clip_depth, 10);
	  cube([thickness, wall_thickness, 10]);
	}
}

module container_bottom() {
	translate([0, -size_outer/2, 0]) {
		cube([size_outer, size_outer, wall_thickness]);
	}
	translate([0, 0, wall_thickness]) {
		translate([size_outer/2, 0, 0])
		difference() {
			cylinder(r=outer_radius - wall_thickness - clearance, h=distance_between_ports);
			translate([0, 0, -1]) cylinder(r=outer_radius - wall_thickness*2, h=distance_between_ports+5);
		}
		translate([clip_offset, size_outer/2, 0]) clip(thickness=clip_thickness, clip_depth=clip_depth);
		translate([size_outer - clip_thickness - clip_offset , size_outer/2, 0]) clip(thickness=clip_thickness, clip_depth=clip_depth);
		mirror(v=[0,1,0]) {
			translate([clip_offset, size_outer/2, 0]) clip(thickness=clip_thickness, clip_depth=clip_depth);
			translate([size_outer - clip_thickness - clip_offset, size_outer/2, 0]) clip(thickness=clip_thickness, clip_depth=clip_depth);
		}

		holder_depth=1;
		holder_width=25;
		port_depth=7;
		port_width = 12.5;
		hole_clearance = 2.5;
		translate([2*outer_radius - holder_depth - port_depth, -holder_width/2, 0])
		difference() {
			union() {
				cube([holder_depth, holder_width, cylinder_height - distance_between_ports]);
				translate([0, holder_width, 0]) cube([port_depth, 5, cylinder_height-distance_between_ports]);
				translate([0, -5, 0]) cube([port_depth, 5, cylinder_height-distance_between_ports]);
			}

			union() {
				for (bit=[0:(ports - 1)]) {
					current_height = sum_up_to(port_sizes, bit) + (bit + 1)*distance_between_ports;
					dist_to_hole = (port_sizes[bit] - mounting_hole_dist[bit]) / 2;
					translate([-1, holder_width/2, current_height + dist_to_hole]) {
						rotate([0, 90, 0]) cylinder(r=1.5, h=100);
						translate([0, 0, mounting_hole_dist[bit]]) rotate([0, 90, 0]) cylinder(r=1.5, h=100);
						translate([0, -(port_width) / 2, hole_clearance]) cube([100, port_width, mounting_hole_dist[bit] - 2*hole_clearance]);
					}
				}
				translate([-(2*outer_radius - holder_depth - port_depth), -(-holder_width/2), 0]) translate([size_outer/2, 0, 0])
				difference() {
					cylinder(r=100, h=450);
					translate([0, 0, -1]) cylinder(r=outer_radius - wall_thickness - clearance, h=500);
				}
			}
		}
	}
}

module ccube(size = [1,1,1], center = false)
{
  sz = (len(size) == 3)?size:[size,size,size];
  if (len(center) == 1)
    cube(size, center);
  else
    translate([center[0]?-sz[0]/2:0,center[1]?-sz[1]/2:0,center[2]?-sz[2]/2:0])
    cube(size);
}


module keycap() {
	translate([0, 0, -1]) difference() {
		scale([12, 7, 15]) sphere(d=1);
		union() {
			ccube([cut, cut, cut], center=[true, true, false]); 
		}
	}
	rotate([0, 180, 0]) ccube([12, 7, 1], center=[1, 1, 0]);
	translate([-5.8/2, 0, 0]) ccube([1, 2.5, 3], center=[1, 1, 0]);
	translate([5.8/2, 0, 0]) ccube([1, 2.5, 3], center=[1, 1, 0]);
}

/* color([1, 1, 0]) */
translation_outer = -outer_radius - wall_thickness - clearance;


module extracase() {
	difference() {
		ccube([size_outer, size_outer, 61.5], center=[1, 1, 0]);
		translate([0, 0, 1.5]) ccube([size_outer-3, size_outer-3, cut], center=[1, 1, 0]);
		translate([0, 0, -1]) cylinder(d=15, h=cut);
	}
	
}


/* rotating_cylinder(); */
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

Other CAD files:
src/modules/info_001_serial_number/3d/case.scad
src/modules/info_002_indicators/3d/case.scad
src/modules/puzzle_colored_words/3d/case.scad
src/modules/puzzle_cookware/3d/case.scad
src/modules/puzzle_maze/3d/case.scad

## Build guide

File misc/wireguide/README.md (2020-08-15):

# Wireguide

The original plan of connecting the CAN-modules was to use an ethernet cable:
we would strip the outer layer of the cable where we want to connect a module,
then put on an IDC connector. We would then use one twisted pair for CAN data, and
the other pairs for 12v. We wanted to use an ethernetcable because we have a lot of
spare ethernetcable that's too good to throw away, but too long to be practical.
The CAN specifications also demand a twisted cable.

So in theory, this was a great solution. Unfortunately, theory and practice are
the same in theory, but not in pracice: connecting the IDC connectors proved to be
very time-intensive (first stripping the outer cable, then partially untwisting the strands
and putting them in the correct order) and error-prone (the slightest issue in alignment
	will cause two strands to become electrically connected).

To partially fix this, we designed a small tool that would be able to more easily keep
the strands lined up before pressing the IDC-connector together. This also proved
to be rather hard, so we gave up and just ordered some automotive twisted wire that is
made for CAN traffic.

The term you'll need when trying to buy this twisted wire is `canbus wire`.

`wireguide.scad` is a parametric model of a tool to put the individual wires of an ethernet-cable in the correct position to easily attach an IDC-connector (vampire tap)

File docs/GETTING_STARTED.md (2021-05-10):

# Getting started

This is a guide for writing your own puzzle module. We'll first start by
describing an OBUS game, then describe the minimum things you need to implement
to get a working puzzle module. We'll then finish by explaining some nice-to-haves
(like using info modules or game state in a puzzle module).

## OBUS game

### Parts of the game

The goal of OBUS is to defuse a bomb by communicating clearly. There are (at least) two players: the defuser and the expert.
The defuser can see and interact with the bomb, the expert can read the manual that describes how to defuse the bomb.
You win the game by defusing the bomb, you lose if the bomb explodes. The bomb is defused when all puzzle modules are
solved; the bomb explodes if the time runs out or too much mistakes ("strikes") have been made.

The bomb consists of a controller and multiple modules: the controller shows the time left, the amount of mistakes made
while defusing the bomb (strikes) and the amount of strikes left. It's responsible for starting games, enumerating modules,
keeping track of game state, ...
The modules on the other hand are the parts of the bomb that can be interacted with by the defuser. There are several kinds of
modules: puzzle modules, needy modules and info modules.

Puzzle modules are the most common kind of modules. The bomb is defused as soon as all puzzle modules are solved.
Puzzle modules are generally solved by having the defuser observe some kind of state of the game, then having them
communicate that information to the expert. The expert then uses this information and the manual to communicate a set of
instructions to the defuser. If the instructions are correct and the defuser executes them correctly, the module is solved.
If one of the two players makes an error and the defuser executes an incorrect action, the module generates a "strike".

An example of a puzzle module is an RGB led with a red and a green button under it. The defuser looks at the module and
sees that the RGB led is colored blue. They then tell that to the expert, who then looks up this module in the manual.
The manual instructs to press the green button if the color starts with the letter "b" or "o". The expert then asks the
defuser to press the green button. When the defuser does this, the module is solved.

There are also needy modules. These can't be "solved", but they can generate strikes: they require periodic action
from the defuser to prevent them from generating a strike.

An example of a needy module is a buzzer with a red button. If the buzzer goes off, the defuser has to press the button within 5 seconds
or a strike is generated. Needy modules can also have the expert look something up in the manual (if you do this, make sure
to balance the time needed by the defuser against the time between the signal that action is needed and the strike).

Finally, there are also info modules. These don't serve a purpose on their own, they are only useful in combination with
puzzle or needy modules. They provide extra information to those modules. These modules were added to the game
to make it possible to make puzzle/needy modules with less hardware: puzzle modules generally consist of two "parts":
a part that shows information to the defuser that needs to be communicated to the expert and a part that the defuser
can interact with to solve the module. With info modules, this first part can be moved to a dedicated module that can
be shared between multiple puzzle modules.

An example of an info module is an LCD display that displays a serial number. There can then be a puzzle module with
just two buttons on it. When the defuser is solving that module, the expert reads in the manual "press the second button
if the last digit of the serial number is even, otherwise press the first". The expert then asks for the serial number
and after that has the defuser press the correct button, solving the puzzle module.

### Hardware

In our OBUS implementation, every module has its own microcontroller and CAN module. CAN is a hardware protocol
that allows the modules to communicate with the controller (and each other). To write your own module, you don't
have to know how CAN works, this is all abstracted away with the OBUS framework. The only thing you need to do
is to set the type (puzzle/needy/info) of the module and it's ID. The combination type/ID needs to be unique across
the OBUS game, so in order to avoid collisions, you can register your module in TODO LINK MOANA and get an ID.

In addition to a CAN module, every module also has an RGB LED. This LED is used to show both the
state of the module and to indicate if the module has an error.
If the module is solved, the LED is green, if a module generates a strike, the module blinks red. There are also several blinking
patterns for errors. In order to save pins on the microcontroller for implementing the puzzle, only the red and green
parts of the RGB led are connected. You CANNOT use the RGB LED for the puzzle itself: this would be confusing for the player
and when debugging a game.

### A sample game

This is a description of a sample game with only one module: the `puzzle_testmodule_buttons`. When reading this part, it's useful to have the `puzzle_testmodule_buttons.ino` file next to you as well.

We'll start this story from the start: the puzzle module boots up.
It calls the `obus_module::setup` function to register its module type and ID. It then keeps calling the `obus_module::loopPuzzle` in a loop.
It's important that the `loopPuzzle` function is executed very frequently without delays: if this doesn't happen enough, important CAN messages can get dropped.

Then after a while, a button gets pressed on the controller and the controller starts preparing to start the game. It first asks all info modules to broadcast their information. After some time, it then asks all puzzle/needy module to register themselves. The controller then confirms that that module will be active in the next round with an ACK message. After some time, the controller broadcasts that the game has started and starts counting down.

This broadcasts is received on the puzzle module and results in the `callback_game_start` function getting called the next time the
`obus::loopPuzzle` is called. The `callback_game_start` function is responsible for setting up the module for a new game. Here, we
randomly turn the blue LED on or off, and enable the main loop to start checking button presses.

After the `callback_game_start` function returns, the microcontroller stays inside the `loop` function, and keeps executing the `obus_module::loopPuzzle`
frequently. If the correct button is pressed, it calls the `obus_module::solve` function and turns off input checking. Turning off imput checking is
important: that way it's impossible for the puzzle module to generate strikes after it has been solved. If an incorrect button is pressed, it calls the
`obus_module::strike` function. That function will send a strike to the controller.

When `obus_module::solve` is called, the module sends an "I'm solved" CAN packet to the controller. The controller then sees that all modules have been solved,
and broadcasts a "solved" packet to every module. The next time the `obus_module::loopPuzzle` function gets called, the
`callback_game_stop` will be called. This function is responsible for tearing down the puzzle state. This should have the
same effect as just resetting the microcontroller, so if your state is too hard to clean up, you can just reboot the microcontroller.

## What you need to implement for your own puzzle module

- The setup code, initializing your microcontroller and setting the type and id of the module with `obus_module::setup`
- The main loop code. This should call the `loopPuzzle` function frequently so that all CAN packets can be handled.
- A call to the `obus_module::solve` function
- A description for the expert of how to defuse the module in `doc/index.md` of your module folder
- The `callback_game_start` and `callback_game_stop` functions. These can be empty.

Some tips:

- If you are using calls to `delay()`, try to replace them with a timer (a variable that keeps track of when something should happen).
  That way the function that handles CAN messages (`loopPuzzle`) can continue executing, without the microcontroller being stuck in the `delay()` function.
	The `loopPuzzle` function will automatically put itself into an error state if it has been too long since it has been called. This is meant to make
	writing correct code easier: that way you discover your code needs to be rewritten easily instead of having to figure out that and why messages are dropped.
- Every time you play the game, it should be different (otherwise the defuser could just memorize what to do, this would be no fun for the experts).
  To accomplish this, you can use the `random()` function. You don't need to seed it (we recommend against it), because the OBUS framework already
	seeds this for you every game. That way, we can replay games for debugging if needed.

## More advanced puzzle modules

### Receiving game updates

It's possible to use the current state of the game in your module: the amount of
strikes, amount of allowed strikes and time left (in milliseconds) regularly get
broadcast to all modules. That way, you can spice up your puzzle, for example by
making the defuser press a button when the countdown timer has a `1` in it, or by
having the instructions in the manual vary based on the amount of strikes.

See `docs/snippet_timeleft.cpp` for how to use the time remaining on the countdown
timer in your module.

### Using info modules in your puzzle/needy modules

Using info modules is a great way to reduce the amount of hardware components needed in a puzzle:
you can then still have puzzles that change every game, without having to add components that show information
to the defuser. Info modules broadcast their information to all modules in the phase before the game starts.
Every module can listen to these info messages with the `callback_info` callback. This callback will get
the ID of the info module and 7 bytes, as specified by the specific module. The `callback_info` function is
responsible for filtering out the info messages the module is interested in, and saving that info for the upcoming game.

For example, the serial number module has ID 1 and sends in its message 7 random character, chosen randomly from numbers
and the uppercase letters.

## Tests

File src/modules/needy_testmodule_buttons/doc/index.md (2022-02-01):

# Testmodule needy buttons

Als de module geluid maakt, druk op de knop.

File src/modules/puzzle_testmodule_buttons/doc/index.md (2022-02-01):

# Testmodule knoppen

Als de LED aan is, druk op de groene knop, anders op de rode knop.

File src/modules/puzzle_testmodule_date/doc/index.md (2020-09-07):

## Testmodule buttons

Don't press the red button. Press the green button to solve the module.

### Credits
Module developed by redfast00.

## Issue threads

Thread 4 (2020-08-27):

CAN debugging module also listen for CAN bus errors/overflows

redfast00, 2020-08-27:

Closed 2022-06-23.

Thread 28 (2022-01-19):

Add "clear" button in web debugger

redfast00, 2022-01-19:
This state (the index before which messages should not be displayed) should be kept client-side, so different people can have different views.

redfast00, 2022-01-25:
Fixed in https://github.com/ZeusWPI/OBUS/commit/e97cb6f8edc9d7e0f07ba96bf0638625bb1ace03

Closed 2022-01-25.

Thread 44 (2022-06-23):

Investigate pin 10 digitalread causing crash in cookware module

redfast00, 2022-06-23:
If digital pin 10 is read in the loop in the cookware module, the microcontroller crashes

redfast00, 2022-06-24:
@chvp https://github.com/arduino/ArduinoCore-avr/blob/master/libraries/SPI/src/SPI.cpp#L47 *runs*

redfast00, 2022-06-24:
Maar in my defense, het is wel misleidend van de mcp2515 mensen om een CS pin te vragen als constructor in hun klasse, en die dan ook te gebruiken, maar tegelijk ook nog dingen te doen met de Arduino ingebouwde CS pin

Closed 2023-11-23.

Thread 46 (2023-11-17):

Stop beeping sound when bomb explodes or is solved before the timer deadline

redfast00, 2023-11-17:

Closed 2023-11-23.

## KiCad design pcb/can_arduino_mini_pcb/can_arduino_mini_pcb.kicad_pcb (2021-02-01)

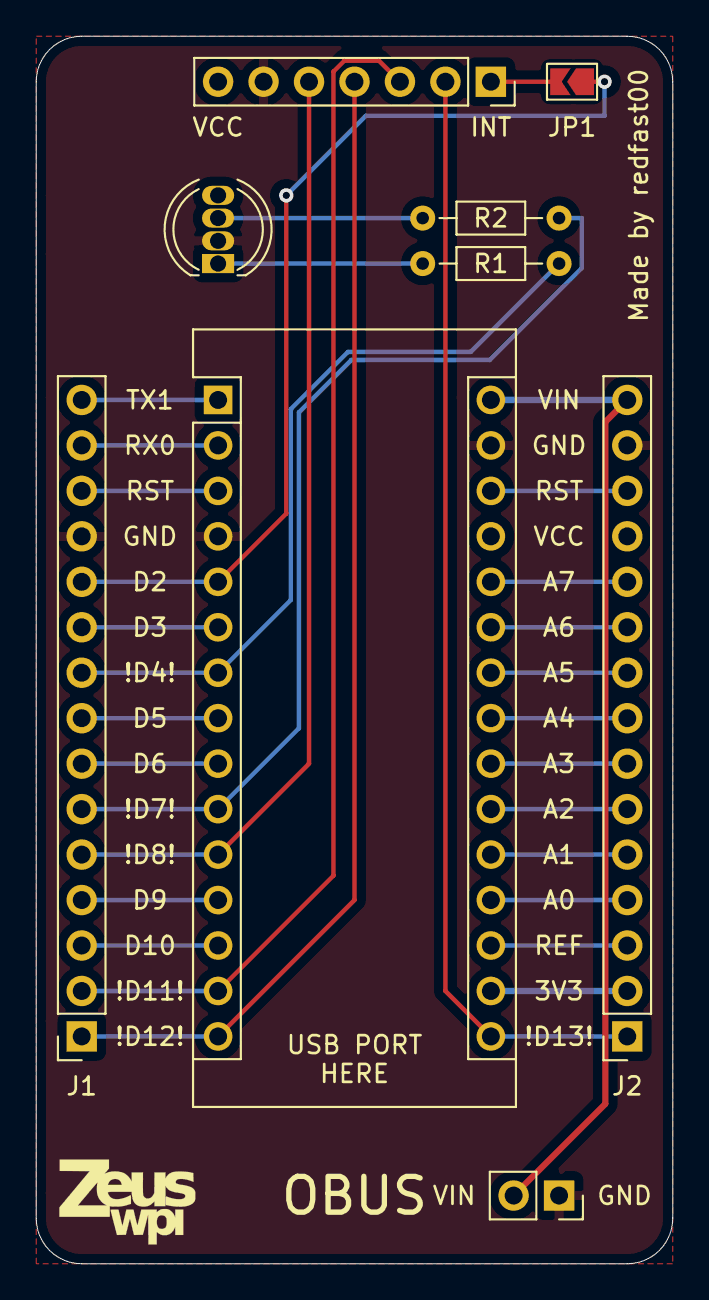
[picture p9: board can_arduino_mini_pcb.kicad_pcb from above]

Board: 2 copper layers, 35.6 x 68.6 mm, 10 parts (0 on the bottom side), 32 nets.

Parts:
A1: Arduino_Nano_v3.x; Arduino_Nano
D1: LED_RCGB; LED_D5.0mm-4_RGB
J1, J2: Conn_01x15_Female; PinSocket_1x15_P2.54mm_Vertical
J3: Conn_01x02_Female; PinSocket_1x02_P2.54mm_Vertical
J4: Conn_01x07_Female; PinSocket_1x07_P2.54mm_Vertical
JP1: Jumper_NO_Small; SolderJumper-2_P1.3mm_Open_TrianglePad1.0x1.5mm
R1, R2: 330; R_Axial_DIN0204_L3.6mm_D1.6mm_P7.62mm_Horizontal
U1: CAN_MODULE; logo_small

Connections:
+3V3: A1.17, J2.2
+5V: A1.30, J2.15, J3.2
GND: A1.4, A1.29, D1.2, J1.12, J2.14, J3.1, J4.6
unnamed: A1.1, J1.15
unnamed: A1.2, J1.14
unnamed: A1.3, J1.13
unnamed: A1.5, J1.11, JP1.1
unnamed: A1.6, J1.10
unnamed: A1.7, J1.9, R1.2
unnamed: A1.8, J1.8
unnamed: A1.9, J1.7
unnamed: A1.10, J1.6, R2.2
unnamed: A1.11, J1.5, J4.5
unnamed: A1.12, J1.4
unnamed: A1.13, J1.3
unnamed: A1.14, J1.2, J4.3
unnamed: A1.15, J1.1, J4.4
unnamed: A1.16, J2.1, J4.2
unnamed: A1.18, J2.3
unnamed: A1.19, J2.4
unnamed: A1.20, J2.5
unnamed: A1.21, J2.6
unnamed: A1.22, J2.7
unnamed: A1.23, J2.8
unnamed: A1.24, J2.9
unnamed: A1.25, J2.10
unnamed: A1.26, J2.11
unnamed: A1.28, J2.13
unnamed: D1.1, R1.1
unnamed: D1.3, R2.1
unnamed: J4.1, JP1.2
VCC: A1.27, J2.12, J4.7

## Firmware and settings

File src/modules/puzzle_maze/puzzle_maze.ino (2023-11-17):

// (c) 2022, redfast00, jasper_janin, robbe7730, Pietervdvn
// See the LICENSE file for conditions for copying

#include <obus_module.h>
#include <obus_util.h>
#include "LedControl.h"
#include "ezButton.h"

#define LED_DIN_PIN 3
#define LED_CLK_PIN 2
#define LED_CS_PIN 5

#define UP_BUTTON A0
#define DOWN_BUTTON A1
#define LEFT_BUTTON A2
#define RIGHT_BUTTON A3

#define BLINK_INTERVAL 250
#define GOL_STATES 4
// yellow = up A0
Debounced upButton = Debounced();
// blue = down A1
Debounced downButton = Debounced();
// orange = left A2
Debounced leftButton = Debounced();
// green = right A3
Debounced rightButton = Debounced();

int current_x;
int current_y;

int target_x;
int target_y;
int blink_timeout = 0;
long last_time = 0;

int selected_maze;

bool led_state = true;

bool playing = false;

#define NUM_MAZES 4
#define MAZE_SIZE 64

// From bottom to top
uint8_t mazes[MAZE_SIZE*NUM_MAZES] = {
  // MAZE 1
  0b1111, 0b1111, 0b1111, 0b1111, 0b1111, 0b1111, 0b1111, 0b1111,
  0b1111, 0b0011, 0b1110, 0b0111, 0b1011, 0b0010, 0b0110, 0b1111,
  0b1111, 0b0001, 0b0010, 0b1100, 0b0011, 0b0100, 0b1101, 0b1111,
  0b1111, 0b0101, 0b1001, 0b0010, 0b0100, 0b1001, 0b0110, 0b1111,
  0b1111, 0b0101, 0b0011, 0b1100, 0b1001, 0b0110, 0b1101, 0b1111,
  0b1111, 0b1101, 0b0101, 0b1011, 0b1010, 0b0000, 0b0110, 0b1111,
  0b1111, 0b1011, 0b1000, 0b1110, 0b1011, 0b1100, 0b1101, 0b1111,
  0b1111, 0b1111, 0b1111, 0b1111, 0b1111, 0b1111, 0b1111, 0b1111,
  // MAZE 2
  0b1111, 0b1111, 0b1111, 0b1111, 0b1111, 0b1111, 0b1111, 0b1111,
  0b1111, 0b0011, 0b0010, 0b0110, 0b0111, 0b0111, 0b0111, 0b1111,
  0b1111, 0b1101, 0b1101, 0b0101, 0b1001, 0b0000, 0b0100, 0b1111,
  0b1111, 0b0011, 0b0110, 0b0101, 0b0111, 0b1101, 0b0101, 0b1111,
  0b1111, 0b0101, 0b1001, 0b1000, 0b1000, 0b1010, 0b1100, 0b1111,
  0b1111, 0b0001, 0b0010, 0b1110, 0b0011, 0b0110, 0b0111, 0b1111,
  0b1111, 0b1101, 0b1001, 0b1010, 0b1100, 0b1001, 0b1100, 0b1111,
  0b1111, 0b1111, 0b1111, 0b1111, 0b1111, 0b1111, 0b1111, 0b1111,
  // MAZE3
  0b1111, 0b1111, 0b1111, 0b1111, 0b1111, 0b1111, 0b1111, 0b1111,
  0b1111, 0b1011, 0b1011, 0b1011, 0b0110, 0b0111, 0b0111, 0b1111, 
  0b1111, 0b0011, 0b0010, 0b0010, 0b1000, 0b1000, 0b0100, 0b1111,
  0b1111, 0b1101, 0b0101, 0b1001, 0b1110, 0b0011, 0b1100, 0b1111,
  0b1111, 0b0011, 0b1100, 0b0111, 0b0011, 0b1100, 0b0111, 0b1111,
  0b1111, 0b0001, 0b0110, 0b0101, 0b0001, 0b1010, 0b1100, 0b1111,
  0b1111, 0b1101, 0b1101, 0b1001, 0b1000, 0b1010, 0b1110, 0b1111,
  0b1111, 0b1111, 0b1111, 0b1111, 0b1111, 0b1111, 0b1111, 0b1111,
  // MAZE4
  0b1111, 0b1111, 0b1111, 0b1111, 0b1111, 0b1111, 0b1111, 0b1111,
  0b1111, 0b0111, 0b1011, 0b0010, 0b0010, 0b0010, 0b0110, 0b1111,
  0b1111, 0b1001, 0b1010, 0b0100, 0b1101, 0b1101, 0b0101, 0b1111,
  0b1111, 0b1011, 0b0010, 0b1100, 0b1011, 0b0110, 0b0101, 0b1111,
  0b1111, 0b0111, 0b1001, 0b0110, 0b0011, 0b1000, 0b1100, 0b1111,
  0b1111, 0b0011, 0b0110, 0b1101, 0b1001, 0b1010, 0b0110, 0b1111,
  0b1111, 0b1101, 0b1001, 0b1010, 0b1010, 0b1010, 0b1100, 0b1111,
  0b1111, 0b1111, 0b1111, 0b1111, 0b1111, 0b1111, 0b1111, 0b1111,
  
 
};

// Position of the 3 lights on the edge, packed into one uint8
// 0bxxxxyyyy
uint8_t edge_points[NUM_MAZES * 3] = {
  // MAZE 1
  0b01100111, // (6, 7)
  0b00010000, // (1, 0)
  0b01100000, // (6, 0)
  // MAZE 2
  0b00000100, // (0, 4),
  0b00110000, // (3, 0),
  0b01110011, // (7, 3)
  // MAZE 3
  0b00010111, // (1, 7)
  0b00110111, // (3, 7)
  0b00000001, // (0, 1)
  // MAZE 4
  0b00000110, // (0, 6)
  0b01110101, // (7, 5)
  0b00010000 // (1, 0)
};

LedControl lc = LedControl(LED_DIN_PIN, LED_CLK_PIN, LED_CS_PIN, 1);


uint8_t game_of_life_a[8];
uint32_t gol_previous_states[GOL_STATES];
// Time to live: will decrease every GOL-generation
uint32_t gol_auto_reset = 1024;

/**
* 0 = spiral
* 1 = GOL
*/
uint8_t idle_state = 0;  
uint32_t gol_generation = 0;

void(* crash) (void) = 0;

void setup() {
	lc.shutdown(0, false);
	lc.setIntensity(0, 3);
	lc.clearDisplay(0);
	Serial.begin(115200);
	obus_module::setup(OBUS_TYPE_PUZZLE, 0);

  selected_maze = 0;
  current_x = 1;
  current_y = 1;
  target_x = 6;
  target_y = 6;

  pinMode(UP_BUTTON, INPUT_PULLUP);
  pinMode(DOWN_BUTTON, INPUT_PULLUP);
  pinMode(LEFT_BUTTON, INPUT_PULLUP);
  pinMode(RIGHT_BUTTON, INPUT_PULLUP);
}

bool connected(int x, int y, int new_x, int new_y) {
  if (x < 0 || new_x < 0 || y < 0 || y < 0 || x > 7 || new_x > 7 || y > 7 || new_y > 7) {
    return false;
  }

  if (x == new_x && y == new_y) {
    return true;
  }
  
  uint8_t walls = mazes[selected_maze*MAZE_SIZE + y*8 + x];

  int dx = new_x - x;
  int dy = new_y - y;

  if ((dx != 0 && dy != 0) || dx > 1 || dx < -1 || dy > 1 || dy < -1) {
    return false;
  } 
  
  if (dy == 1) {
    return ((walls >> 3) & 1) == 0;
  } else if (dx == 1) {
    return ((walls >> 2) & 1) == 0;
  } else if (dy == -1) {
    return ((walls >> 1) & 1) == 0;
  } else if (dx == -1) {
    return (walls & 1) == 0;
  }

  return false;
}

void buttonLoop() {
  int new_x = current_x;
  int new_y = current_y;
  if (upButton.loop(!digitalRead(UP_BUTTON))) {
    new_y += 1;
  }
  if (downButton.loop(!digitalRead(DOWN_BUTTON))) {
    new_y -= 1;
  }
  if (leftButton.loop(!digitalRead(LEFT_BUTTON))) {
    new_x -= 1;
  }
  if (rightButton.loop(!digitalRead(RIGHT_BUTTON))) {
    new_x += 1;
  }

  if (!connected(current_x, current_y, new_x, new_y)) {
    obus_module::strike();
  } else {
		if (current_x != new_x || current_y != new_y) {
			lc.setLed(0, current_x, current_y, false);
		}
    current_x = new_x;
    current_y = new_y;
  }

  if (current_x == target_x && current_y == target_y) {
    Serial.print("Solved!");
    obus_module::solve();
    crash();
  }
}

void clear_screen() {
  for (int x = 0; x < 8; x++) {
    for (int y = 0; y < 8; y++) {
      lc.setLed(0, x, y, false);
    }
  }
}

void draw_edges() {
  for (int i = 0; i < 3; i++) {
    uint8_t pos = edge_points[selected_maze * 3 + i];
    uint8_t x = pos >> 4;
    uint8_t y = pos & 0xf;

    lc.setLed(0, x, y, true);
  }
}

void draw_spiral(uint32_t i) {

  int direction_x = 0;
  int direction_y = -1; // immediately will become direction_x = + 1

  int x = 0;
  int y = 0;

  int drawn = 0;

  while(drawn < i){


    if(x == y){
        direction_x = -direction_y;
        direction_y = 0;

    }else if(x == 7 - y) {
      direction_y = direction_x;
      direction_x = 0;
    }


    if(drawn != 0 && x == y && x < 4){
      y++;
      x++;
    }

    lc.setLed(0, x, y, true);
    drawn ++;
    x += direction_x;
    y += direction_y;


  }

}

int getCell(int x, int y){
  if(x < 0){
    x = 8 + x;
  }
  if(y < 0) {
    y = 8 + y; 
  }
  x = x % 8;
  y = y % 8;
  return (game_of_life_a[x] & (1 << y)) >> y;
}

bool getNextState(int x, int y){
  int sum = getCell(x - 1, y - 1) + getCell(x , y -1) + getCell(x + 1, y - 1)+ 
  getCell(x - 1, y)+ getCell(x + 1, y )+
  getCell(x - 1, y + 1)+getCell(x , y + 1)+getCell(x + 1, y + 1);
  if(getCell(x, y)){
    return sum == 2 || sum == 3;
  }
  return sum == 3;
}

void show_GOL_state() {
  for(int x = 0; x < 8; x++) {
    for(int y = 0; y < 8; y++){
      if(getCell(x, y)){
        Serial.print("O");
      }else{
        Serial.print(" ");
      }
      lc.setLed(0, x, y, getCell(x,y));
    }
    Serial.print("\n");
  }
  Serial.print("\n\n");
}

void game_of_life(int generation){
  show_GOL_state();


  uint8_t game_of_life_b[8] = {0,0,0,0,0,0,0,0};
  for(int x = 0; x < 8; x++) {
    uint8_t bitset = 0;
    for(int y = 0; y < 8; y++){
      if(getNextState(x, y)){
        bitset = bitset | (1 << y);
      }
    }
    game_of_life_b[x] = bitset;
  }
  int sum = 0;
  for(int x = 0; x < 8; x++) {
    game_of_life_a[x] = game_of_life_b[x];
    sum += game_of_life_b[x];
  }
  
  if(sum == 0 && gol_auto_reset > 5){
    gol_auto_reset = 5;
  }
  for(int i = 0; i < GOL_STATES; i++){
    if(gol_previous_states[i] == sum && gol_auto_reset > 25){
      gol_auto_reset =  25;
    }
  }
  gol_auto_reset--;
  if(gol_auto_reset <= 0){
    seed_random();
  }
  gol_previous_states[ generation % GOL_STATES  ] = sum;

}

void seed_random(){
  Serial.print("SEEDING GOL\n");
 for(int x = 0; x < 8; x++) {
      game_of_life_a[x] = random(0, 255) & random(0, 255) & random(0, 255);
    }
}

void seed_glider(){
  Serial.print("SEEDING GOL with glider\n");
      game_of_life_a[0] = 0b01000000;
      game_of_life_a[1] = 0b00100000;
      game_of_life_a[2] = 0b11100000;
    
}


void draw_animation(size_t m) {
  uint32_t time = (m / 200);
  if(idle_state == 0){
    draw_spiral(time  % 65);
    if(time == 64) {
      clear_screen();
      idle_state = 1;
    }
    gol_generation = time;
    seed_random();
  }else {
    if(gol_generation == time){
      return;
    }
    Serial.print(gol_generation);
    Serial.print(" GOL generation\n");
    gol_generation = time;
    game_of_life(gol_generation);
  }

}

obus_can::message message;

void loop() {
	bool is_message_valid = obus_module::loopPuzzle(&message, callback_game_start, callback_game_stop);

  size_t m = millis();
  
  if (playing) {
    buttonLoop();

    blink_timeout -= m - last_time;
    last_time = m;

    if (blink_timeout <= 0) {
      led_state = !led_state;
      blink_timeout = BLINK_INTERVAL;
    }

    lc.setLed(0, target_x, target_y, led_state);

    lc.setLed(0, current_x, current_y, true);
  } else {
    draw_animation(m);
  }
}

void callback_game_start(uint8_t puzzle_modules) {
  playing = true;
  selected_maze = random(NUM_MAZES);

  current_x = random(1, 7);
  current_y = random(1, 7);

  target_x = current_x;
  while (abs(target_x - current_x) <= 2) {
    target_x = random(1, 7);
  }

  target_y = current_y;
  while (abs(target_y - current_y) <= 2) {
    target_y = random(1, 7);
  }

  clear_screen();

  draw_edges();
}

void callback_game_stop() {
    ((void (*)(void))0)();
}

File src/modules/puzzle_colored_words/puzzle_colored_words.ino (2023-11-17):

// (c) 2022, redfast00
// See the LICENSE file for conditions for copying
#include <obus_module.h>
#include <obus_util.h>
#include <Adafruit_GFX.h>                                                                           // Adafruit graphics library
#include <Adafruit_ST7735.h>                                                                        // Adafruit ST7735 display library
#include <SPI.h>


#define TFT_RST 5 // reset line (optional, pass -1 if not used)
#define TFT_CS 6  // chip select line
#define TFT_DC 9  // data/command line
#define YES_BUTTON A0
#define NO_BUTTON A1

Adafruit_ST7735 tft = Adafruit_ST7735(TFT_CS, TFT_DC, TFT_RST);

uint16_t from_rgb(uint32_t rgb) {
	uint16_t red = (rgb >> 16) & 0xff;
	uint16_t green = (rgb >> 8) & 0xff;
	uint16_t blue = rgb & 0xff;

	return ((blue >> 3) << 11) | ((green >> 2) << 5) | (red >> 3);
}

#define AMOUNT_COLORS 7

const char* words[AMOUNT_COLORS] = {
	"ROOD",
	"GROEN",
	"BLAUW",
	"WIT",
	"PAARS",
	"GRIJS",
	"GEEL"
};
#define RED_IDX 0
#define GREEN_IDX 1
#define BLUE_IDX 2
#define WHITE_IDX 3
#define PURPLE_IDX 4
#define GREY_IDX 5
#define YELLOW_IDX 6

const uint32_t colors[AMOUNT_COLORS] = {
	0xff0000,
	0x00ff00,
	0x0000ff,
	0xffffff,
	0x640064,
	0x7f7f7f,
	0xffff33
};
#define PUZZLE_SIZE 8
uint8_t puzzle_colors[PUZZLE_SIZE] = {0};
uint8_t puzzle_words[PUZZLE_SIZE] = {0};
uint8_t press_idx = 0;
bool press_yes = false;

#define LOOP_IDX for (int i = 0; i < PUZZLE_SIZE; i++)
#define LOOP_JDX for (int j = 0; i < PUZZLE_SIZE; j++)

void generate_problem() {
	for (int i = 0; i < PUZZLE_SIZE; i++) {
		do {
			puzzle_colors[i] = random(AMOUNT_COLORS);
			puzzle_words[i] = random(AMOUNT_COLORS);
			// Assign random color and word; re-roll if the color and word are same as the one before
		} while (i > 0 && (puzzle_colors[i] == puzzle_colors[i-1] && puzzle_words[i] == puzzle_words[i-1]));
	}

	switch (puzzle_colors[0]) {
		case RED_IDX: { // red as first color
			LOOP_IDX {
				if (puzzle_colors[i] == puzzle_words[i]) {
					press_idx = i;
				 	press_yes = false;
					return;
				}
			}
			//
			int sum = 0;
			uint8_t possible_index = 0;
			LOOP_IDX {
				if (puzzle_colors[i] == RED_IDX) {
					sum++;
					possible_index = i;
				}
			}
			if (sum >= 2) {
				press_idx = possible_index;
				press_yes = true;
				return;
			}
			//
			press_idx = PUZZLE_SIZE - 1;
			press_yes = false;
			return;
		}
		case GREEN_IDX: { // green as first color
			// Set random (non-first) color to purple
			puzzle_words[random(1, PUZZLE_SIZE)] = PURPLE_IDX;
			// Color is blue and words is green
			LOOP_IDX {
				if (puzzle_colors[i] == BLUE_IDX && puzzle_words[i] == GREEN_IDX) {
					LOOP_JDX  {
						if (puzzle_colors[j] == BLUE_IDX) {
							press_idx = j;
							press_yes = false;
							return;
						}
					}
				}
			}
			// Color is red and (word is grey or yellow)
			LOOP_IDX {
				if (puzzle_colors[i] == RED_IDX && (puzzle_words[i] == GREY_IDX || puzzle_words[i] == YELLOW_IDX)) {
					press_idx = i;
					press_yes = false;
					return;
				}
			}
			// Word is grey and next color is white or green
			for (int i = 0; i < PUZZLE_SIZE - 1; i++) {
				if (puzzle_words[i] == GREY_IDX && (puzzle_colors[i+1] == WHITE_IDX || puzzle_colors[i+1] == GREEN_IDX)) {
					LOOP_JDX {
						if (puzzle_words[j] == GREY_IDX) {
							press_idx = j;
							press_yes = true;
							return;
						}
					}
				}
			}
			LOOP_IDX {
				if (puzzle_words[i] == PURPLE_IDX) {
					press_idx = i;
					press_yes = false;
					return;
				}
			}
			// should never be reached
			return;
		}
		case BLUE_IDX: {
			int ctr = 0;
			LOOP_IDX {
				if (puzzle_colors[i] != puzzle_words[i]) {
					ctr++;
					if (ctr == 4) {
						press_idx = i;
						press_yes = true;
						return;
					}
				}
			}
			for (int i = 0; i < PUZZLE_SIZE - 1; i++) {
				if (puzzle_colors[i] == puzzle_colors[i+1]) {
					press_idx = 2;
					press_yes = false;
					return;
				}
			}
			LOOP_IDX {
				if (puzzle_colors[i] == BLUE_IDX) {
					press_idx = i;
					press_yes = (i == 0);
				}
			}
			return;
		}
		case WHITE_IDX: {
			if (puzzle_words[3] == puzzle_colors[1] || (puzzle_words[3] == puzzle_colors[5])) {
				if (random(2)) {
					puzzle_words[PUZZLE_SIZE - 1] = GREEN_IDX;
				} else {
					puzzle_colors[PUZZLE_SIZE - 1] = GREEN_IDX;
				}
				LOOP_IDX {
					if (puzzle_words[i] == GREEN_IDX || puzzle_colors[i] == GREEN_IDX) {
						press_idx = i;
						press_yes = false;
						return;
					}
				}
			}
			int yellow_ctr = 0;
			int purple_ctr = 0;
			int last_yellow = 0;
			LOOP_IDX {
				if (puzzle_words[i] == YELLOW_IDX) {
					yellow_ctr++;
					last_yellow = i;
				}
				if (puzzle_colors[i] == PURPLE_IDX) {
					purple_ctr++;
				}
				if (yellow_ctr > purple_ctr) {
					press_idx = last_yellow;
					press_yes = false;
					return;
				}
			}
			press_idx = 3;
			press_yes = (puzzle_colors[4] == BLUE_IDX);
			return;
		}
		case PURPLE_IDX: {
			// set one word to white
			puzzle_words[random(PUZZLE_SIZE)] = WHITE_IDX;

			//
			if (puzzle_colors[1] == RED_IDX) {
				press_idx = 1;
				press_yes = true;
				return;
			} else if (puzzle_colors[2] == RED_IDX) {
				press_idx = 2;
				press_yes = true;
				return;
			}
			//
			LOOP_IDX {
				if (puzzle_words[i] == GREY_IDX && puzzle_colors[i] != WHITE_IDX) {
					press_idx = i;
					press_yes = false;
					return;
				}
			}
			//
			LOOP_IDX {
				// Guaranteed to happen
				if (puzzle_words[i] == WHITE_IDX) {
					press_idx = i;
					press_yes = false;
					return;
				}
			}
			return;
		}
		case GREY_IDX: {
			// set one color to purple
			puzzle_colors[random(1, PUZZLE_SIZE)] = PURPLE_IDX;
			for (int i = 0; i < PUZZLE_SIZE - 1; i++) {
				if (puzzle_colors[i] == puzzle_colors[i+1]) {
					LOOP_JDX {
						if (puzzle_colors[j] == GREY_IDX) {
							press_idx = j;
							press_yes = true;
						}
					}
					return; // last grey color
				}
			}
			// press first yellow color and 3 4
			if (puzzle_words[3] == puzzle_colors[4]) {
				LOOP_IDX {
					if (puzzle_colors[i] == YELLOW_IDX) {
						press_idx = i;
						press_yes = true;
						return;
					}
				}
			}
			// last time color is purple
			LOOP_IDX {
				if (puzzle_colors[i] == PURPLE_IDX) {
					press_idx = i;
					press_yes = false;
				}
			}
			return;
		}
		case YELLOW_IDX: {
			puzzle_colors[random(1, PUZZLE_SIZE)] = RED_IDX;
			LOOP_IDX {
				if (puzzle_colors[i] == puzzle_words[i]) {
					press_idx = i;
				 	press_yes = true;
					return;
				}
			}
			//
			int sum = 0;
			uint8_t possible_index = 0;
			LOOP_IDX {
				if (puzzle_colors[i] == YELLOW_IDX) {
					sum++;
					possible_index = i;
				}
			}
			if (sum >= 2) {
				press_idx = possible_index;
				press_yes = true;
				return;
			}
			// guaranteed to happen
			LOOP_IDX {
				if (puzzle_colors[i] == RED_IDX) {
					press_idx = i;
					press_yes = false;
					return;
				}
			}
			return;
		}
	}

}

Debounced yes_button;
Debounced no_button;
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

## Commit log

2020-08-04 Upload wireguide tool
    [wireguide.scad]
2020-08-10 Add deubg module that prints everyting on the bus.
2020-08-10 Make baudrate higher for more responsive prints
2020-08-15 Update on wireguide
2020-08-18 Correct module ID handling: ID only unique per type
    [controller.ino]
2020-08-19 Add debugging Arduino code
2020-08-25 Hardware documentation
    [basic_module.fzz]
2020-08-25 Template: add module type and ID, correct functions
    [main.ino]
2020-08-26 Add basic module with two buttons
2020-08-26 Enable error interrupt
2020-08-31 Correct commented setup call in module template
    [main.ino]
2020-09-07 Use pin 8 everywhere
2020-09-07 Add instruction to set up Arduino IDE for uploading
2020-09-07 Resend hello, print number of modules
2020-09-07 Fix controller module count on display
    [controller.ino]
2020-09-09 Improve LED in module
2021-01-30 Add custom PCB
    [can_arduino_mini_pcb.kicad_pcb, can_arduino_mini_pcb.sch, can_arduino_mini_pcb_panel.kicad_pcb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]
2021-01-31 Change RGB LED pins in docs
    [basic_module.fzz]
2021-02-01 Remove info callback in template, correct casing
    [main.ino]
2021-02-01 Start game with button instead of automatically
2021-02-01 Change field from "puzzles solved" to "… left"
    [controller.ino]
2021-02-01 Fix typos and indentation
    [puzzle_testmodule_buttons.ino]
2021-08-09 Add pressure coupler documentation
2021-08-09 Add ports info module openscad
    [gears.scad, info_ports.scad, servo.scad]
2022-01-12 Printed version of info port module
    [big_gear.stl, container.stl, container_bottom.stl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]
2022-01-12 Add future PCB improvement notes
2022-01-17 Add another note for a new PCB design
2022-01-17 Fix order of operators
    [server.py]
2022-01-19 Add warning that controller is no longer used
    [controller.ino]
2022-01-25 Extrapolate timer, show module state
2022-01-25 Add button to clear logs
2022-02-01 Get properly started on writing manual
    [case.scad]
2022-02-01 Reverse engineered and wired up R455 timer
2022-02-01 Remove panelized PCB, convert to kicad 6
    [can_arduino_mini_pcb_panel.kicad_pcb, can_arduino_mini_pcb_panel.sch]
2022-02-02 PCB idea: add silkscreen with pin names on back
2022-02-03 Add indicators info module
    [case.scad]
2022-02-03 Fix directory structure, minor rewording
    [info_serial_number.ino, puzzle_maze.ino]
2022-02-08 Work some more on maze
    [case.scad]
2022-02-11 Some more notes for new PCB design
2022-02-15 fix callback_game_start in template
    [main.ino]
2022-02-15 add Counter/Timer model 1772
2022-02-15 add Counter/Timer model 1772 module
2022-02-21 Add serial module
    [case.scad]
2022-03-07 Work some more on ports infomodule
    [big_gear.stl, container.stl, container_bottom.stl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]
2022-03-10 Some more info port updates
    [gears.scad, info_ports.scad]
2022-03-10 Write some docs for the ports infomodule
    [info_ports.scad]
2022-03-11 Wiring info
2022-03-15 Add more robust error printing
2022-03-20 Fix callback_game_start and add leds on boundary
    [puzzle_maze.ino]
2022-03-20 Add stop button
2022-06-19 Avoid collisions in CAN messages
    [controller.py]
2022-06-21 Implement controller-side error detection
    [controller.py, obus.py, sketch_can_debugger.ino]
2022-06-23 Fix that every message was an error message
    [controller.py, obus.py]
2022-06-23 Pin 10 is cursed
2022-06-23 Remove debug prints
2023-05-16 Add protocol flow
2023-11-17 Don't redraw position indicator if not needed to avoid flickering
    [puzzle_maze.ino]
2023-11-23 Reset Arduino when controller starts
    [controller.py]
2023-11-23 Disable buttons when cookware module is not running
2023-11-23 Add OpenSCAD designs for cases
    [case.scad, indicator_mount.scad]
2023-11-24 Add ding sound for solved puzzle, show seed
    [controller.py]
2023-12-01 Set flask debug to False to prevent multiple serial threads
    [controller.py]
